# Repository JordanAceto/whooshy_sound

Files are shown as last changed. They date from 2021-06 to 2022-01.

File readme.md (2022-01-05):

# Effects pedal for making whooshy filter and phaser sweeping sounds

## This pedal accommodates various VCF plug-in boards, and contains rich modulation features.

whooshy sound pedal

### [SCHEMATIC](https://github.com/JordanAceto/whooshy_sound/blob/main/hardware/main_pcb/construction_docs/whooshy_sound_main_pcb_schematic.pdf)

---

### Features:
- Guitar pedal style stomp box.
- Can accept a wide variety of [filter plug-in boards](https://github.com/JordanAceto/VCF_plug_in_boards).
    - For guitars and other instrument-level signals I recommend starting with the "2164" filter plug-in boards, because these have very low noise and CV feedthrough.
    - Other plug-in boards will work for guitars, but may be a little noisier and thumpier than you wish. Try them out, they vary.
    - If you're using this in an effects loop or after a preamp, it doesn't matter as much and any of them will probably be fine.
- Manual frequency and resonance controls.
- Digitally generated LFO with morphing waveshaper, smoothly crossfades from triangle to sine to square to sample & hold.
- Analog envelope follower for when you want to quack and bwow instead of whoosh.

---

### Status of the project:

Revision | schematic | pcb layout | firmware | built and tested | safe to order boards
------|--------------|-----------|------------|---------|---------
0.1 | &#9745; | &#9745; | &#9745; | &#9745; | &#9745;

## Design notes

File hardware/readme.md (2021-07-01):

# The hardware for the pedal.

- The [main pcb](https://github.com/JordanAceto/whooshy_sound/tree/main/hardware/main_pcb) is the heart of the project.

- Once the pedal is built, you need at least one [VCF plug-in board](https://github.com/JordanAceto/VCF_plug_in_boards/tree/0e87489fe4cad95ea398019b08850a9033277694) to complete the project.

- Various filter plug-in boards can be swapped in and out to experiment with sounds.

- The [front panel](https://github.com/JordanAceto/whooshy_sound/tree/main/hardware/front_panel) and [jack panel](https://github.com/JordanAceto/whooshy_sound/tree/main/hardware/jack_panel) are simple pcb panels as a cheap way to get an ok looking finished project.

- To build the pedal, you'll need flying wires from the main pcb to the 1/4" jacks, 9 volt DC power entry, and bypass footswitch. A wiring diagram for this is in the [offboard wiring](https://github.com/JordanAceto/whooshy_sound/tree/main/hardware/offboard_wiring) directory.

- [Drill guides](https://github.com/JordanAceto/whooshy_sound/tree/main/hardware/drill_guides) may help when drilling out the Hammond 1590BBS enclosure.

- Note that with a plug-in board installed the circuitboards are just a _liiiiitle_ bit too tall to fit into a Hammond 1590BB. Make sure to get an enclosure that is deep enough, like a 1590BB**S**.

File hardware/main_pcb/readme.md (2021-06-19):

# Main PCB

## The main PCB contains:
- input and output audio buffers
- a software generated LFO
- an envelope follower
- a port which accepts various VCF plug-in boards
- power supply components

---

### PCB front view:
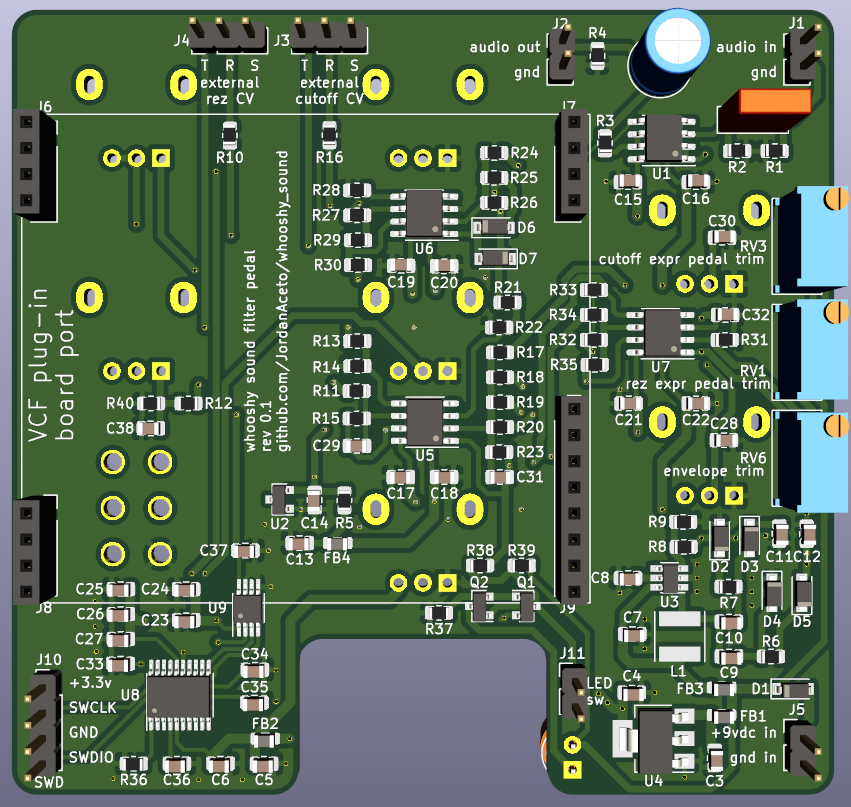
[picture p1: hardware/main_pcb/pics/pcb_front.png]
main PCB front view
 

---

### PCB rear view:
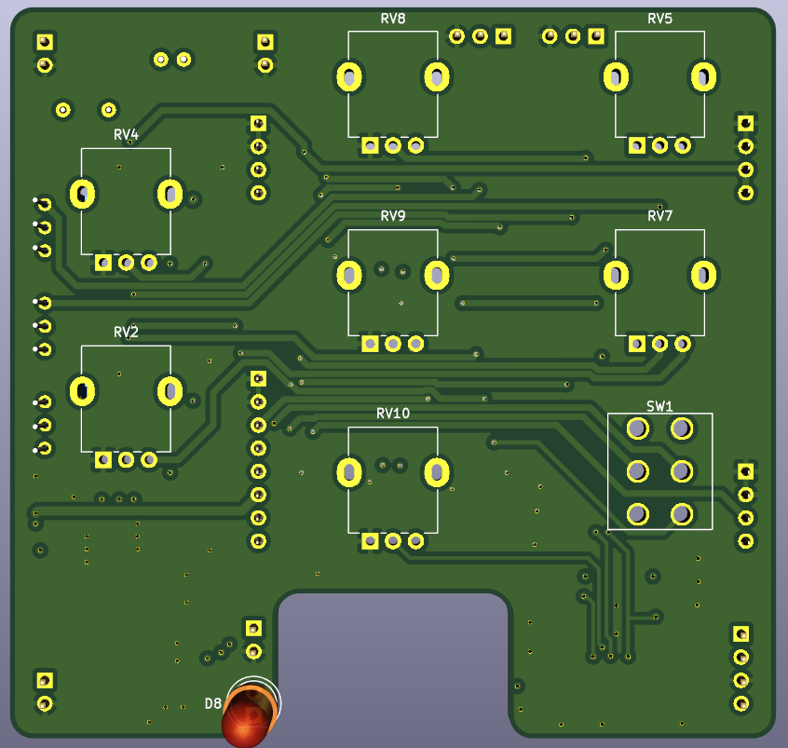
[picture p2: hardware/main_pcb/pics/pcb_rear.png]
main PCB rear view


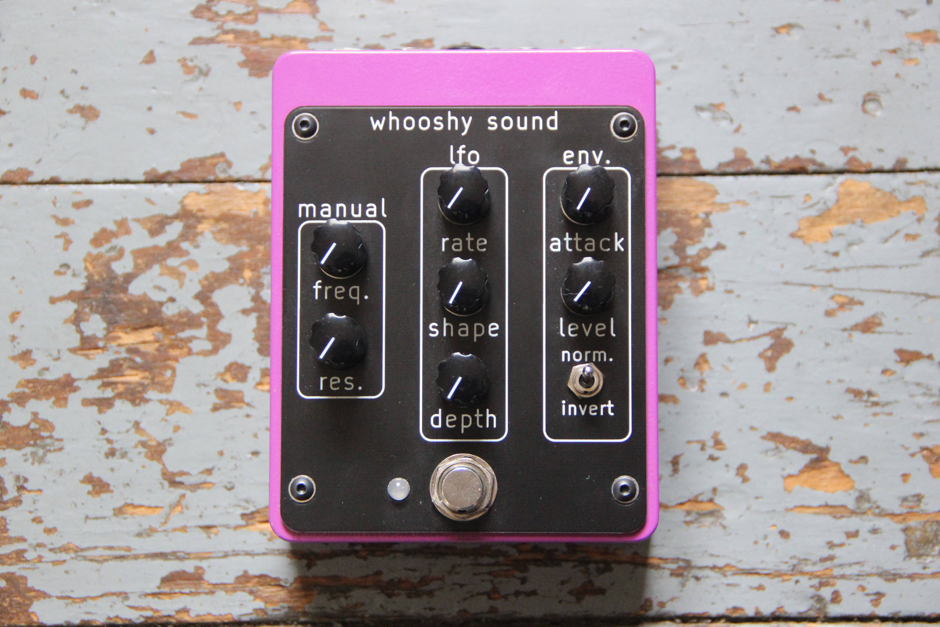
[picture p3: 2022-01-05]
hardware/pics/whooshy_sound_front.JPG

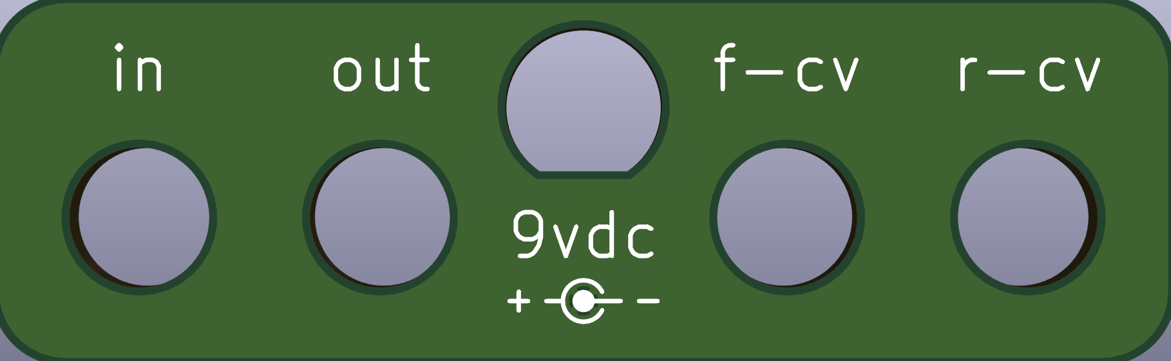
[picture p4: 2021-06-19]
hardware/jack_panel/pics/jack_panel.png

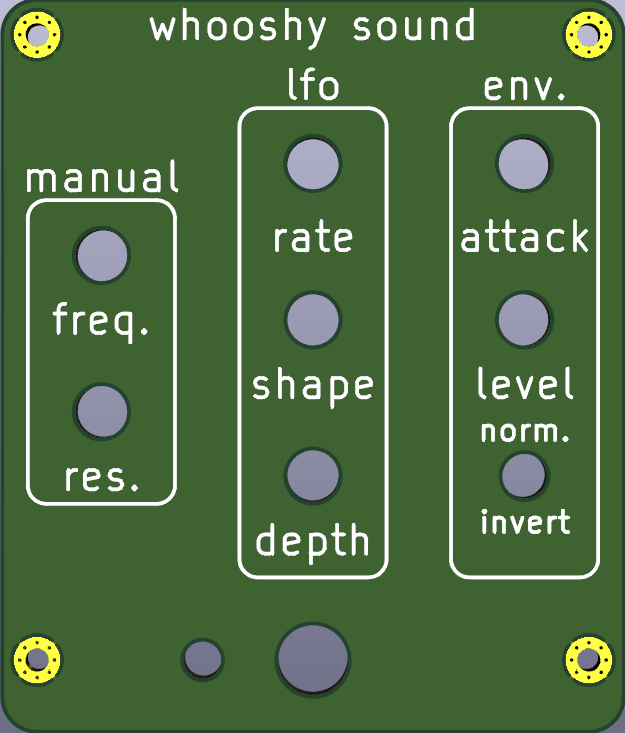
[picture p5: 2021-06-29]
hardware/front_panel/pics/front_panel.png

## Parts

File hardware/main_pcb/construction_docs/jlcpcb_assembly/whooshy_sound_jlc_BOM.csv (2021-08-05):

Comment | Designator | Footprint | LCSC Part Number
TL072 | U7,U6,U5,U1 | SOIC-8_3.9x4.9_1.27P | C6961
1k2 | R40, R3, R30 | 0805 | C17379
2k7 | R12 | 0805 | C17530
1M | R39,R4 | 0805 | C17514
100k | R38,R35,R33,R32,R29,R28,R27,R26,R25,R24,R23,R19,R18,R15 | 0805 | C17407
100R | R37 | 0805 | C17408
MMBT3904 | Q2,Q1 | SOT-23-3 | C20526
10k | R36,R16,R10 | 0805 | C17414
270k | R34, R20 | 0805 | C17589
2k2 | R31,R5 | 0805 | C17520
15k | R22 | 0805 | C17475
120k | R21 | 0805 | C17436
68k | R13 | 0805 | C17801
220k | R17,R11 | 0805 | C17556
27k | R14 | 0805 | C17593
1R | R7,R6 | 0805 | C25271
2M2 | R2,R1 | 0805 | C26113
Bead | FB4,FB3,FB2,FB1 | 0805 | C1015
1N4148W | D7,D6 | SOD-123 | C81598
B5819W | D1 | SOD-123 | C8598
1u | C37,C10,C9,C5 | 0805 | C28323
100n | C36,C35,C34,C33,C30,C28,C27,C26,C24,C22,C21,C20,C19,C18,C17,C16,C15,C14,C13,C8,C6 | 0805 | C49678
2u2 | C32 | 0805 | C49217
22n | C31,C29 | 0805 | C1729
10u | C38, C25,C23,C4,C3 | 0805 | C15850
4u7 | C12,C11,C7 | 0805 | C1779

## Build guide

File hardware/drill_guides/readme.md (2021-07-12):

## Printable drill guides

Various file types are provided, they are all the same thing.

I have had the best luck printing to scale by opening up the .gbr file with kicads gerber-viewer and printing from there.

Make sure to measure/compare it to the actual hardware before drilling anything!



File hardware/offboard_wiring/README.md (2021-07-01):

# Offboard wiring

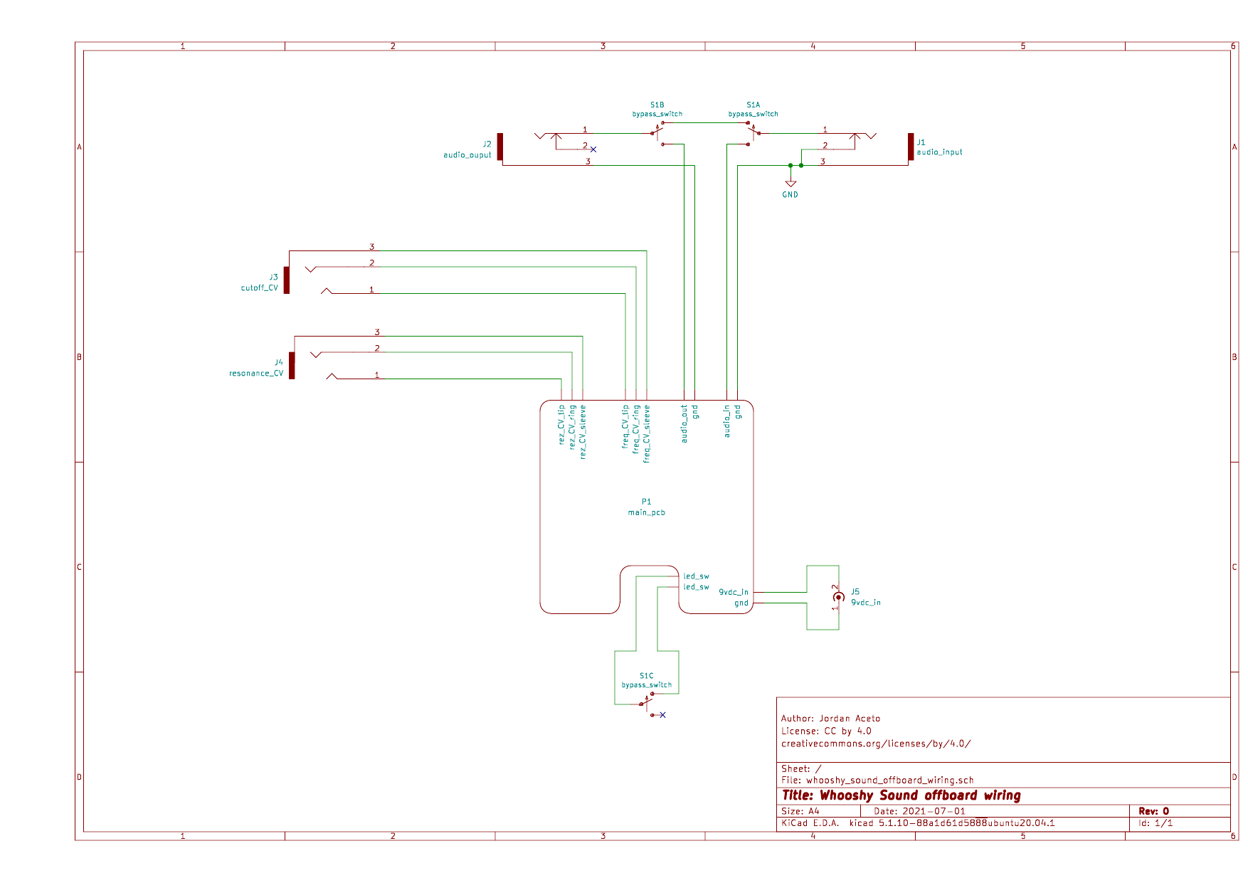
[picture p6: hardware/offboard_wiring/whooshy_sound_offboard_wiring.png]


This directory simply contains a wiring diagram for the offboard components that
are wired to the main pcb with flying wires.

These components are:
- signal input and signal output jacks
- 9vdc power input jack
- bypass switch
- cutoff-frequency and resonance CV input/expression pedal jacks

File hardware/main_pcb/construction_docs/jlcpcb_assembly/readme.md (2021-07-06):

# Files for low cost [JLCPCB smt assembly](https://jlcpcb.com/smt-assembly)

## Note that not all smt components are included! A few small parts will need to be hand soldered.

### Missing parts include:
- STM32L031F4
- MCP4821
- LT3467A
- PMEG2010 diodes
- DC-DC converter inductor
- DC-DC convererter feedback resistors
- LM4040
- LT1117

The above parts were not in stock at the time of order.

If you are using the JLCPCB assembly service in the future, check on those parts and see if they are back in stock. Also be sure to check that other parts have not gone out of stock.

The assembly saves hand soldering almost 90 parts for about ~$4.50 per board (which included the cost of the parts). Whether this is worth it or not is up to you.

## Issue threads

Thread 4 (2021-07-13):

DAC shutdown pin is wrong

JordanAceto, 2021-07-13:
D'oh, the shutdown pin for the DAC is tied to ground, but this permanently shuts down the device.

As a kludge, carefully bend pin 6 of the DAC up, and tie it to 3.3v somehow.

Please eventually respin the main pcb and fix this issue by tying pin 6 of the MCP4821 DAC to logical high instead of low.

Consider changing the footprint to SOIC8 when you do this, there is no pressing need for the smaller MSOP footprint.

JordanAceto, 2021-08-05:
Done.

Closed 2021-08-05.

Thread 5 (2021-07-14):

toggle switch and footswitch holes are too small in the front panel

JordanAceto, 2021-07-14:
The holes for the envelope-follower invert/normal switch and the bypass footswitch are a little too small on the front panel.

This is not a very big problem, because you can easily ream or drill out the holes to be slightly bigger.

Still, if you do a new batch of front panels, make the holes the correct size please.

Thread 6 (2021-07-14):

Envelope follower level pot feels off

JordanAceto, 2021-07-14:
The envelope follower level pot attenuates the envelope signal that sits in the range [0v, +2v].

When you turn it down, it goes down to zero volts.

This feels weird with the way everything is scaled, it would feel more natural if it turned "down" towards +1 volt (the middle of its range), squishing peaks down and pushing valleys up. This is how the LFO is attenuated, it swings between 0 and +2 volts, centered around +1 volt, and attenuates to +1 volt.

As a quick fix, cut the ground leg of the envelope follower pot and inject a +1 volt reference. This could be created by a 2.7k / 1.2k resistive voltage divider across the +3.3v rail. Put a big cap across at least one of the resistors. If you do this, consider also changing the EF level pot to 100k, the bigger the pot to more attenuation you'll get when you turn it down. There still might be some EF bleed when the pot is at a minimum.

When a pcb respin happens, consider ways of scaling the EF to accomplish the attenuation behavior described above. Maybe this means rethinking the norm/invert switch and the method of generating the offset. Perhaps the EF could swing from [-1v, +1v], centered around zero, and then get pushed up 1 volt later in the CV summing amp.

Bonus points if you can change the norm/invert switch to a single pole switch while you do this, I bet you can.

If it seems like the best way to do this is to add another opamp, you could use the other half of a dual package for the LED driver and get rid of the existing transistor LED driver.

JordanAceto, 2021-08-05:
Done, centered envelope follower around +1v. I did not change the invert switch to a single pole version, but I thought about how to do it right after I ordered boards. Just apply the +1v reference directly to the non-inverting input of the opamp, and get rid of the bias applying resistor that gets switched in. Oh well, add this in some other time.

Closed 2021-08-05.

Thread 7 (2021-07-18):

Envelope follower invert switch should say "up/down"

JordanAceto, 2021-07-18:
On the front panel, the envelope follower invert switch is labeled "norm./invert".

To be more intuitive to users, this should be changed to "up/down".

Not a big deal, change it if you're making other changes to the front panel also.

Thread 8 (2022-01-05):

Envelope follower invert switch does not need to be DPDT

JordanAceto, 2022-01-05:
The envelope follower normal/invert switch is currently a DPDT switch.

The same thing could be accomplished with a SPDT or SPST switch.

Instead of grounding the non-inverting opamp input and applying a bias to the inverting input, just short the non-inverting input to a +1 volt DC reference or leave it open.

This is not a pressing issue, just consider it if/when a board revision happens.

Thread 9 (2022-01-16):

CV signals should be clipped to [0v .. +2v]

JordanAceto, 2022-01-16:
The useful range of the cutoff CV is [0v .. +2v]. Voltages outside this range that reach the VCF plug-in boards will not cause any electrical harm, but it can sometimes cause thumping or other offset issues depending on the filter. This especially happens when the envelope follower trim is set for higher gain than is necessary and the envelope follower is turned up really high.

The user can avoid bad sounding settings by adjusting things correctly, but it would be an improvement to prevent them from making big DC thumps in the first place.

Please add some  kind of clamping circuit so that the control voltages can not exceed the range [0v .. +2v]. A half a volt or so in either direction is also fine, this is not a precise clamp, just a way to stop grossly wrong control signals from hitting the filters.

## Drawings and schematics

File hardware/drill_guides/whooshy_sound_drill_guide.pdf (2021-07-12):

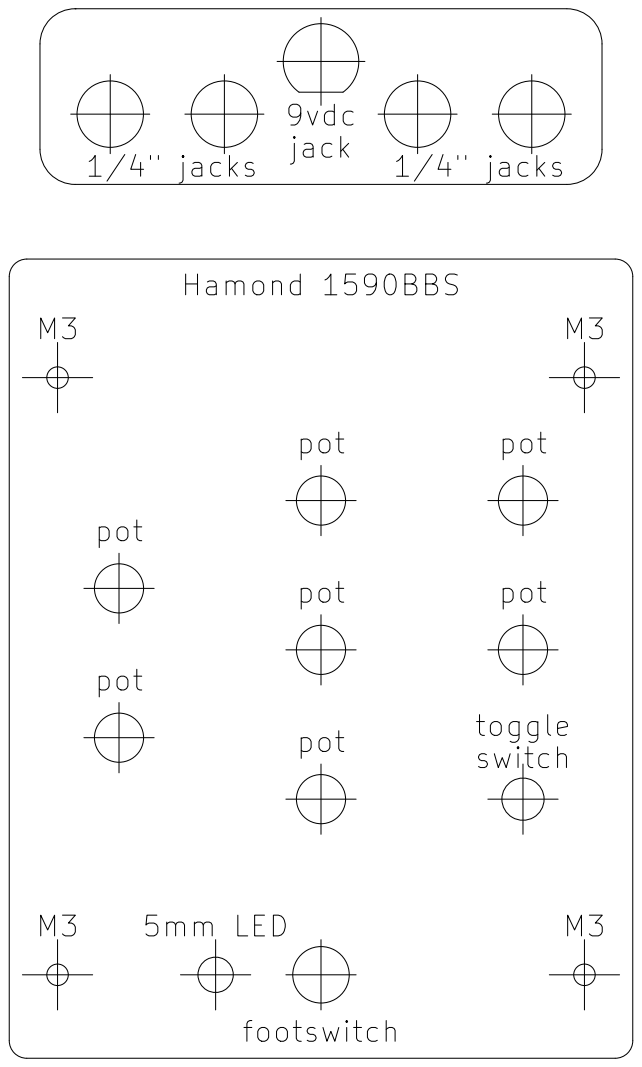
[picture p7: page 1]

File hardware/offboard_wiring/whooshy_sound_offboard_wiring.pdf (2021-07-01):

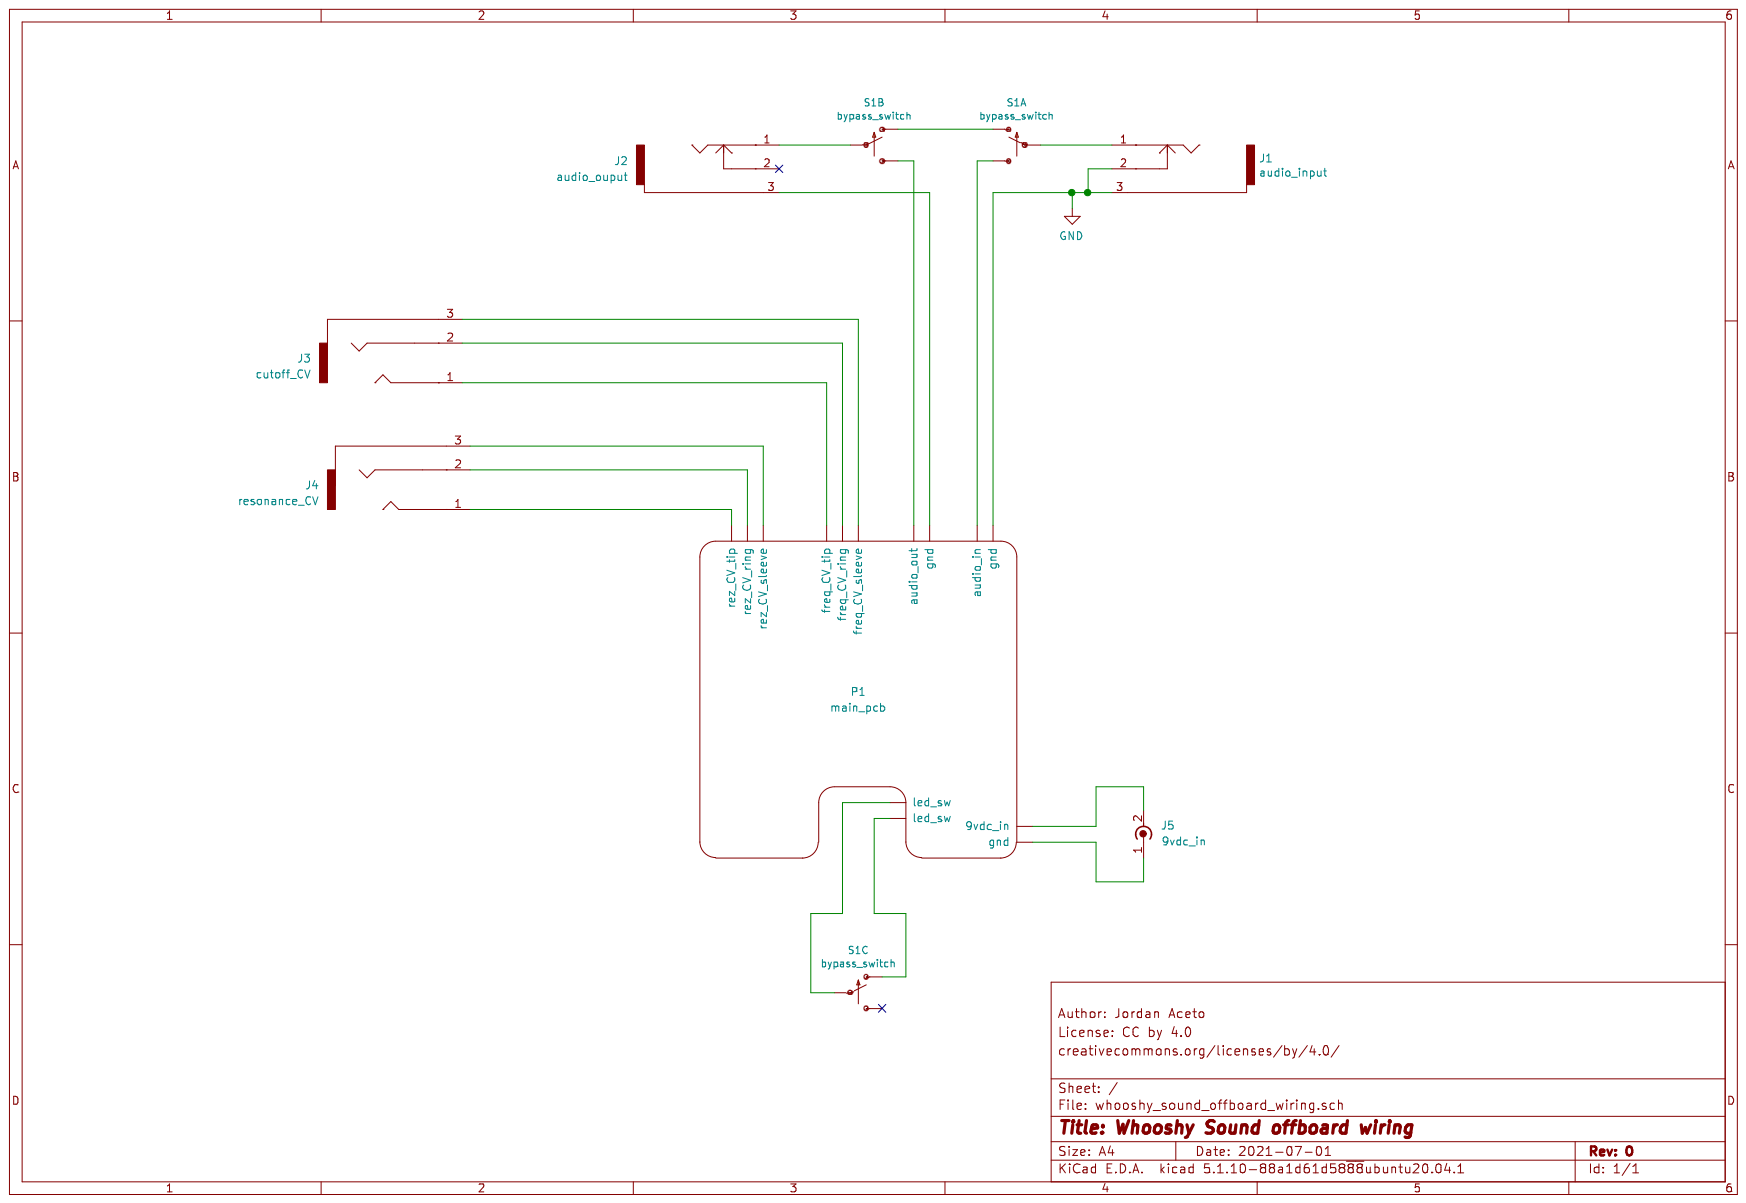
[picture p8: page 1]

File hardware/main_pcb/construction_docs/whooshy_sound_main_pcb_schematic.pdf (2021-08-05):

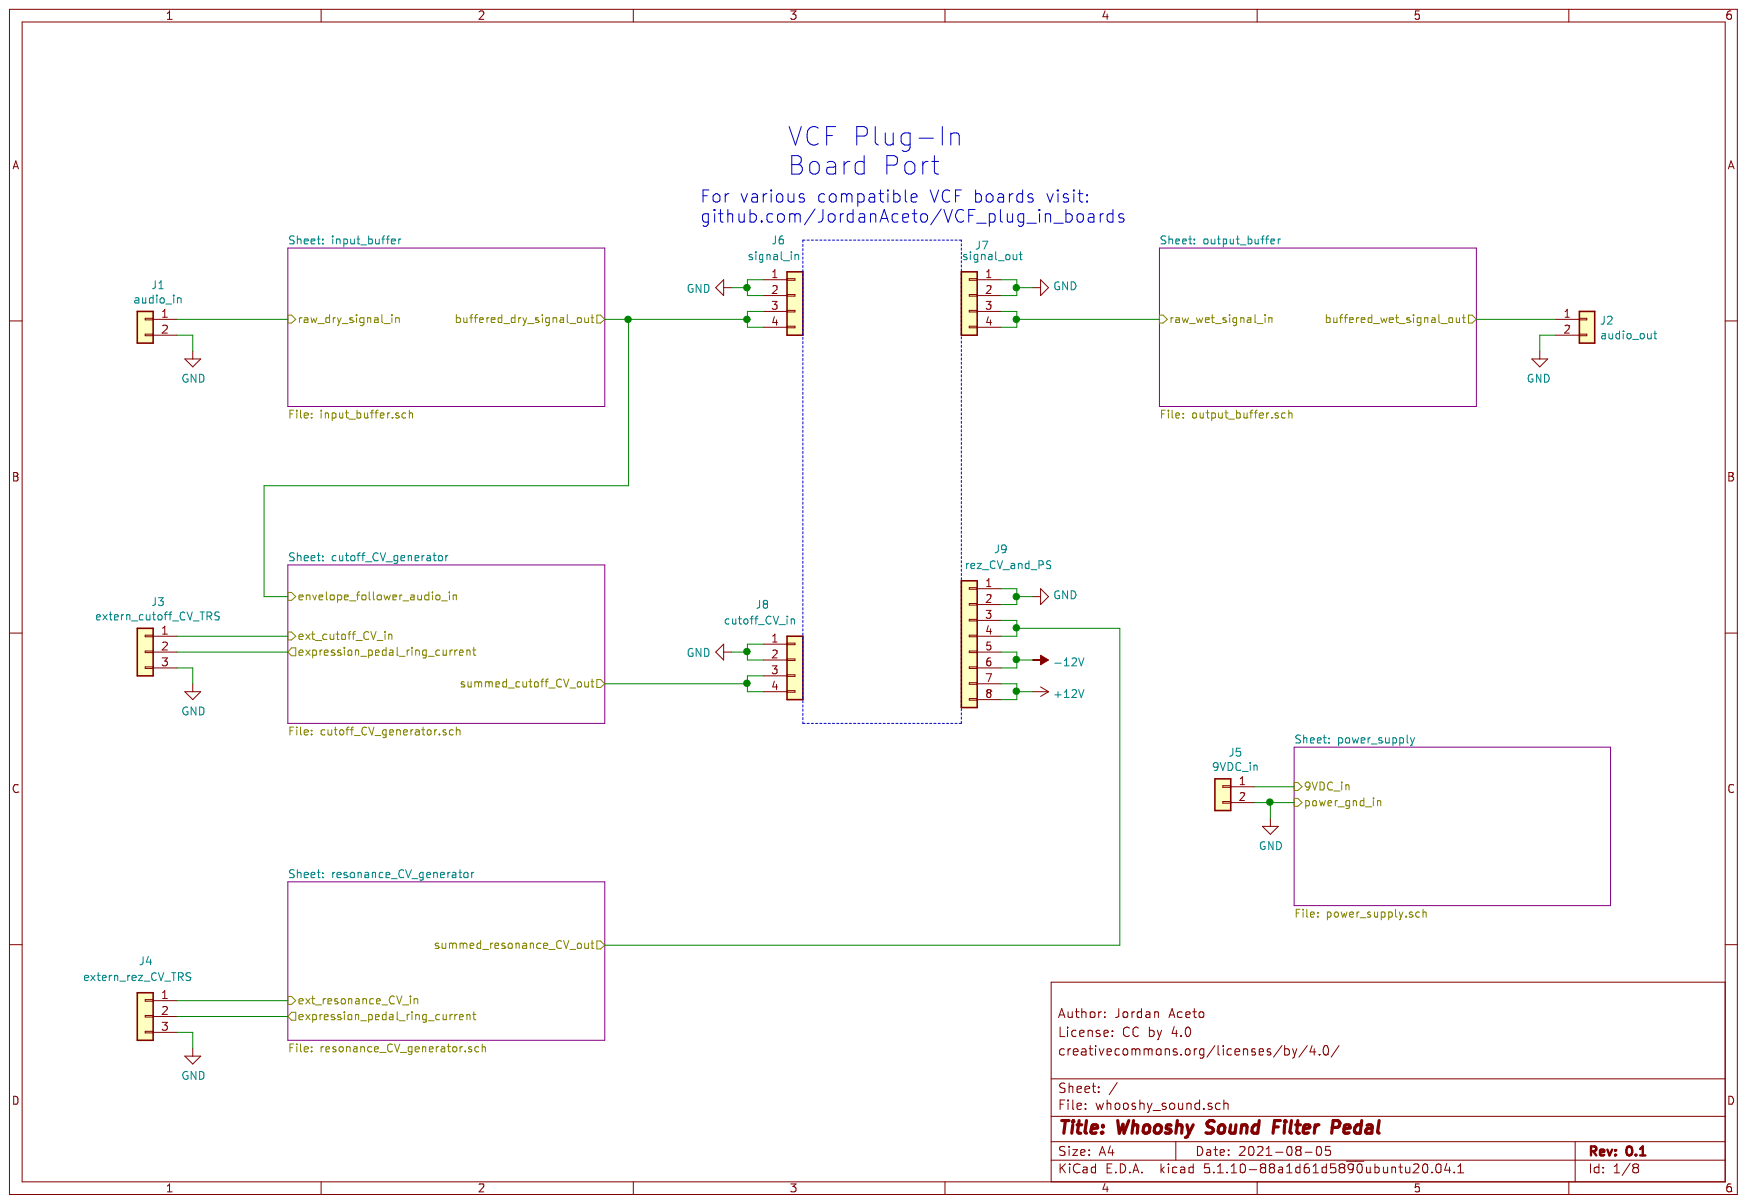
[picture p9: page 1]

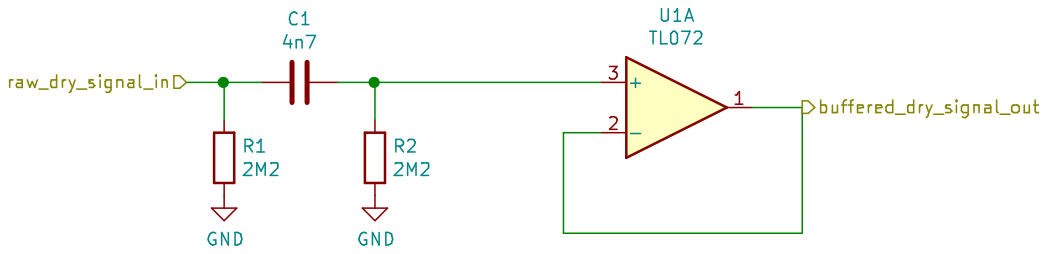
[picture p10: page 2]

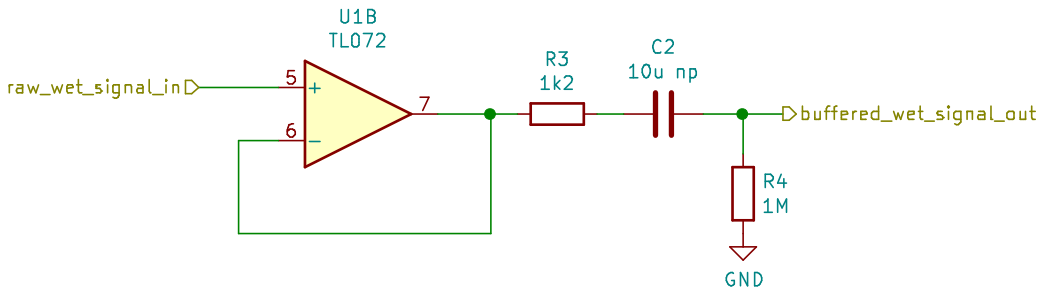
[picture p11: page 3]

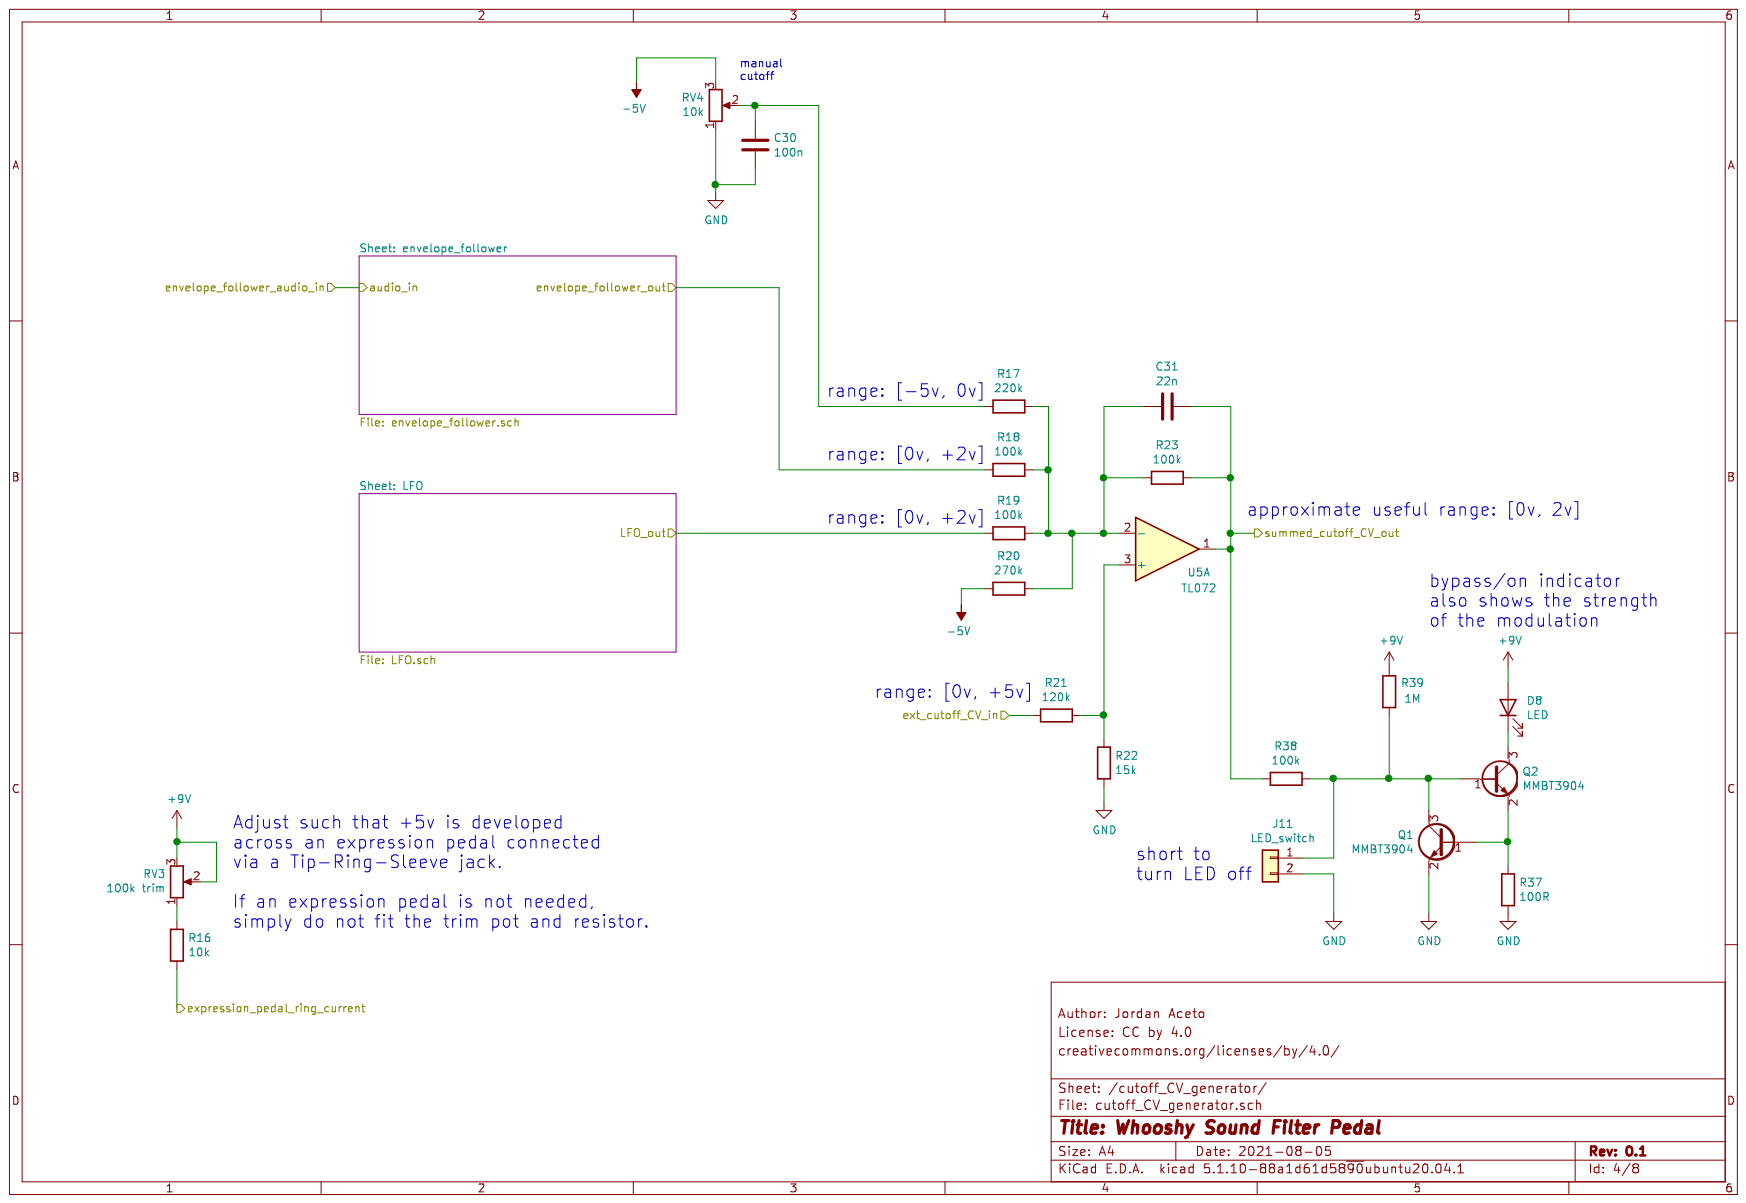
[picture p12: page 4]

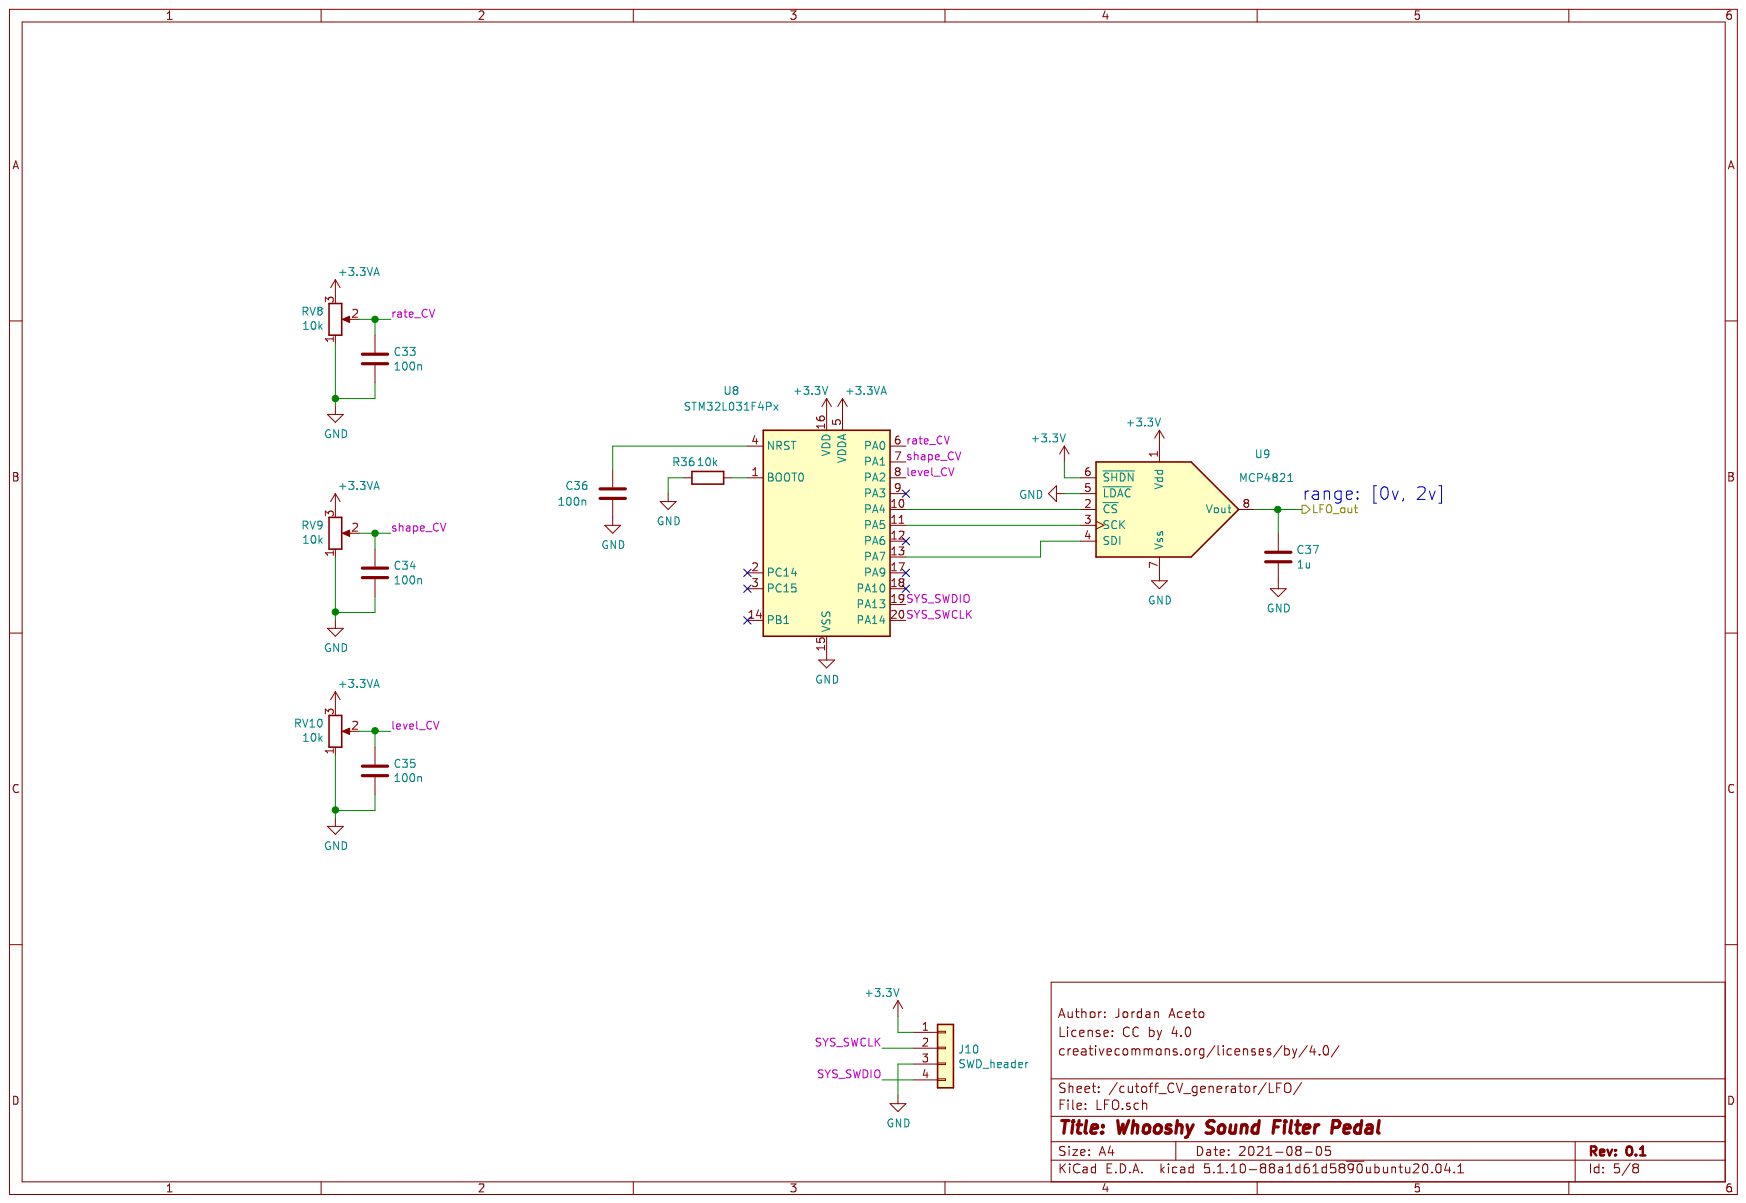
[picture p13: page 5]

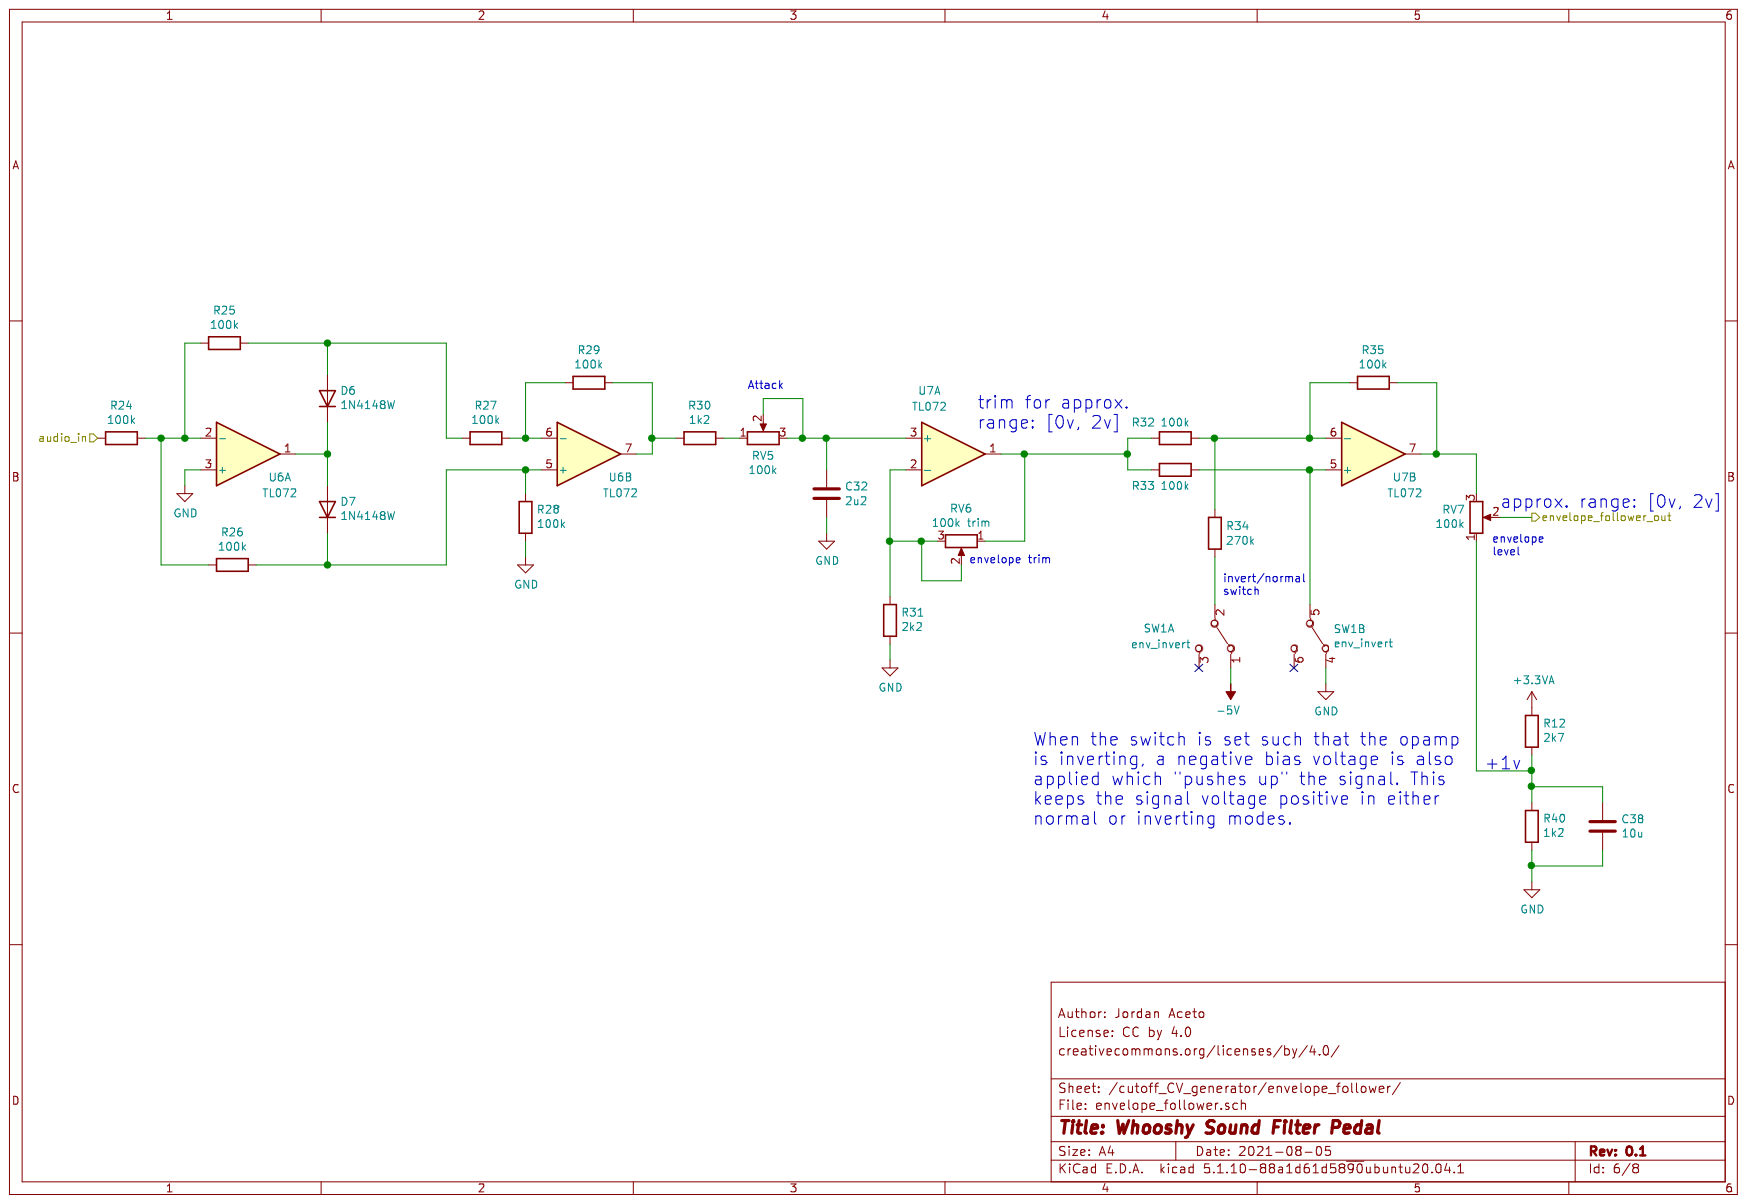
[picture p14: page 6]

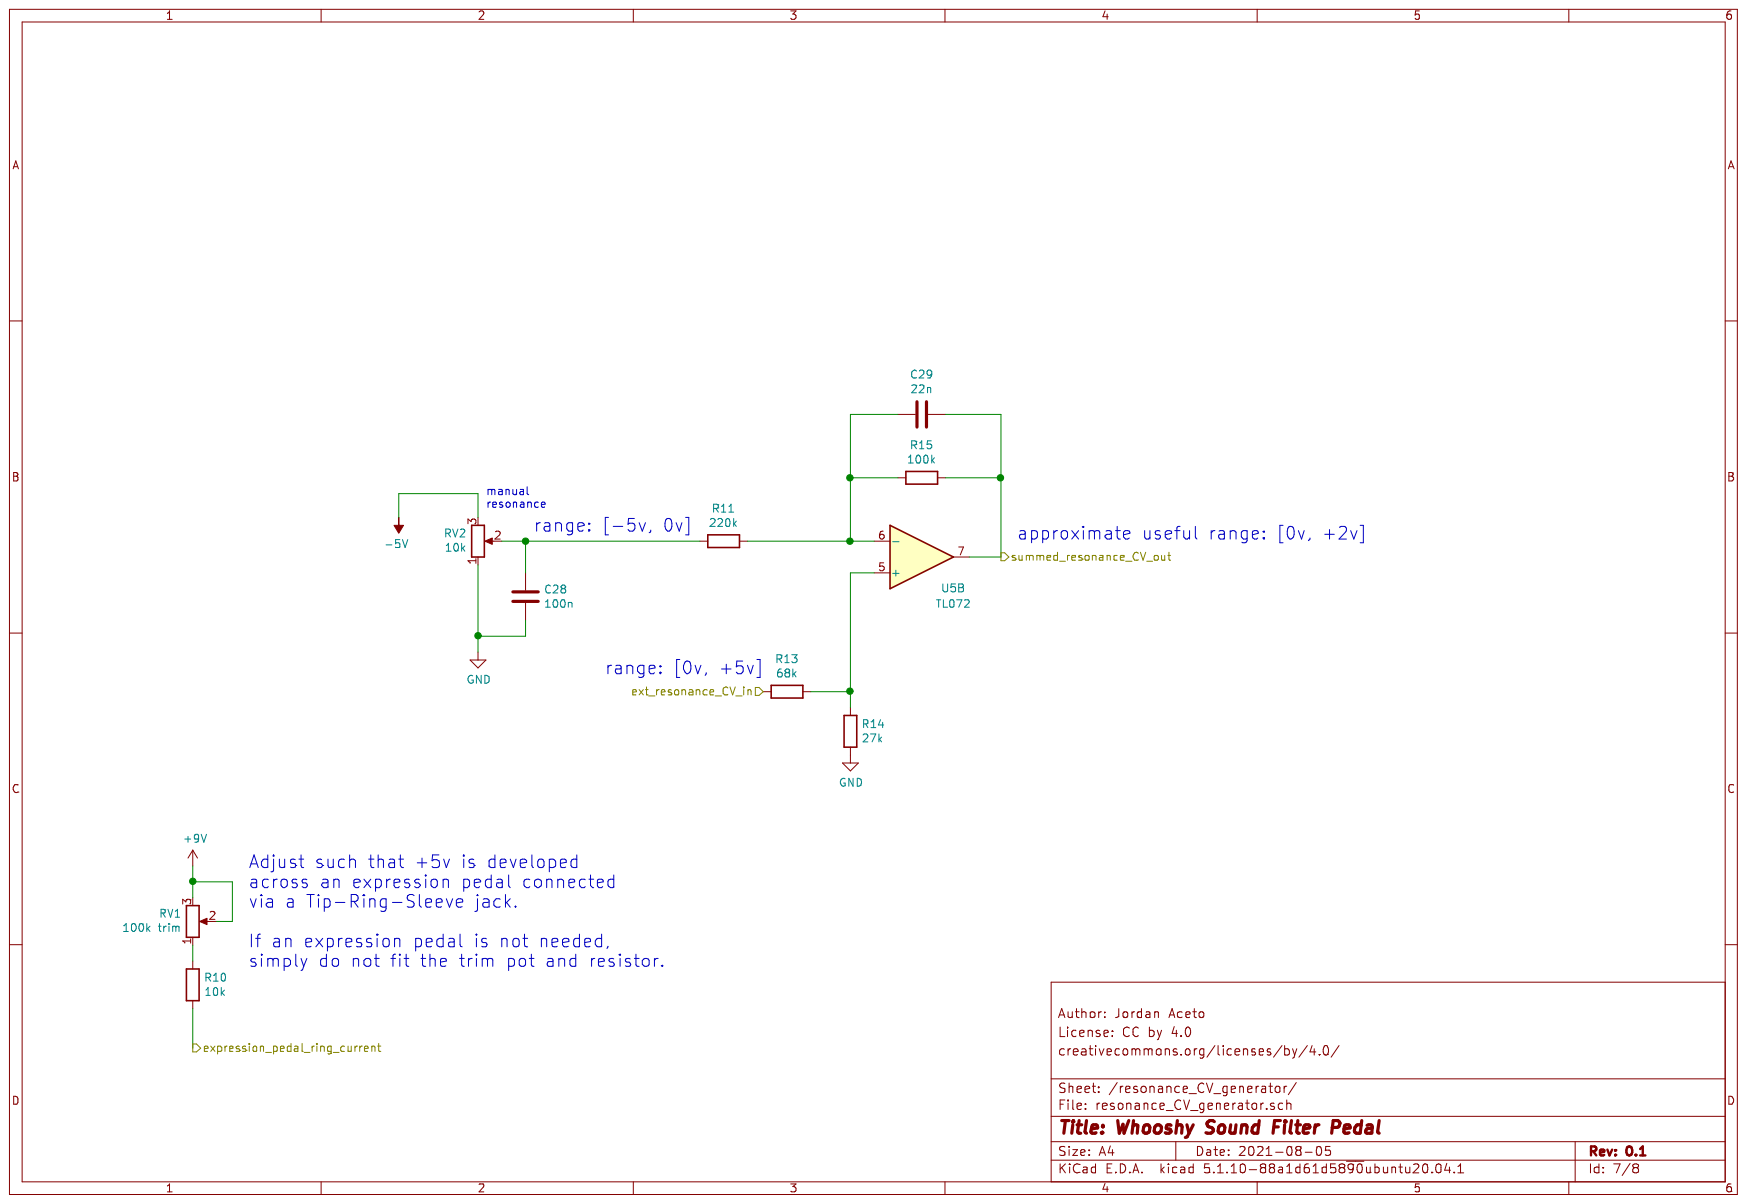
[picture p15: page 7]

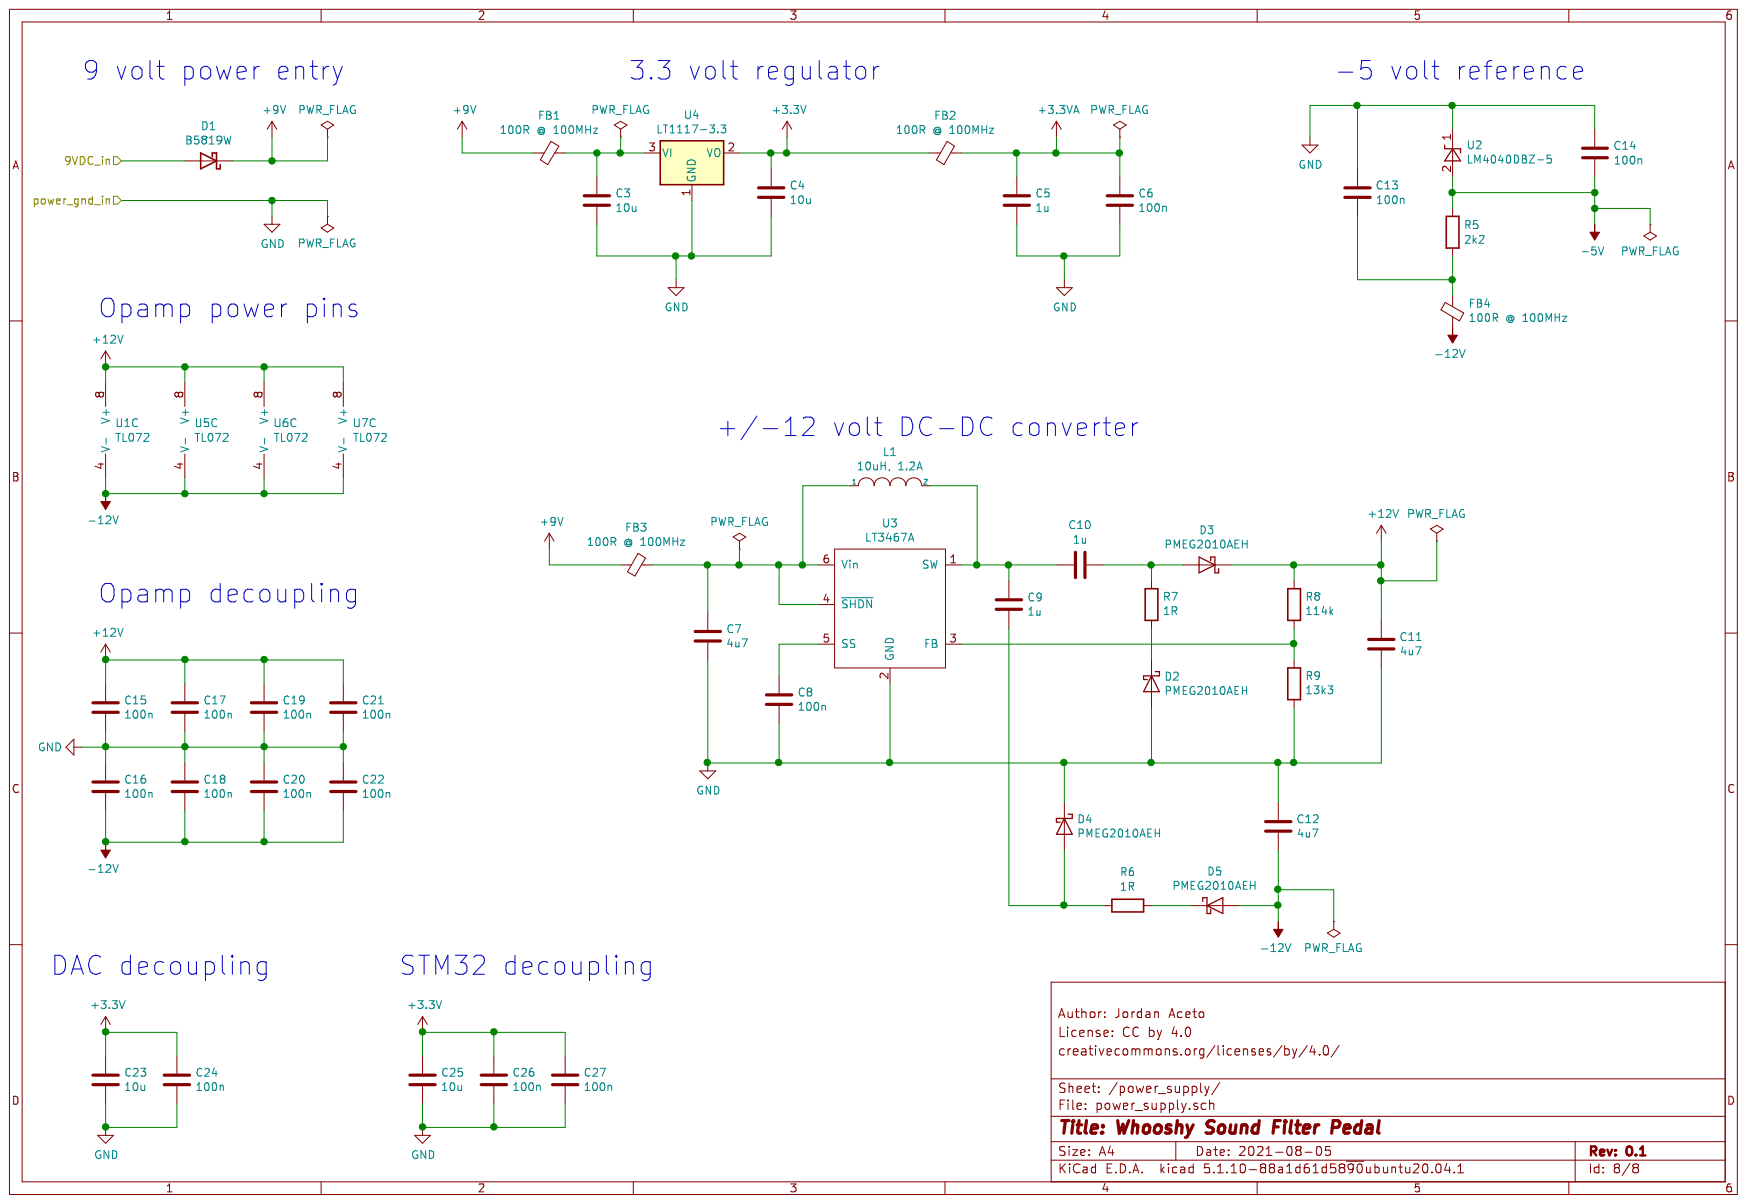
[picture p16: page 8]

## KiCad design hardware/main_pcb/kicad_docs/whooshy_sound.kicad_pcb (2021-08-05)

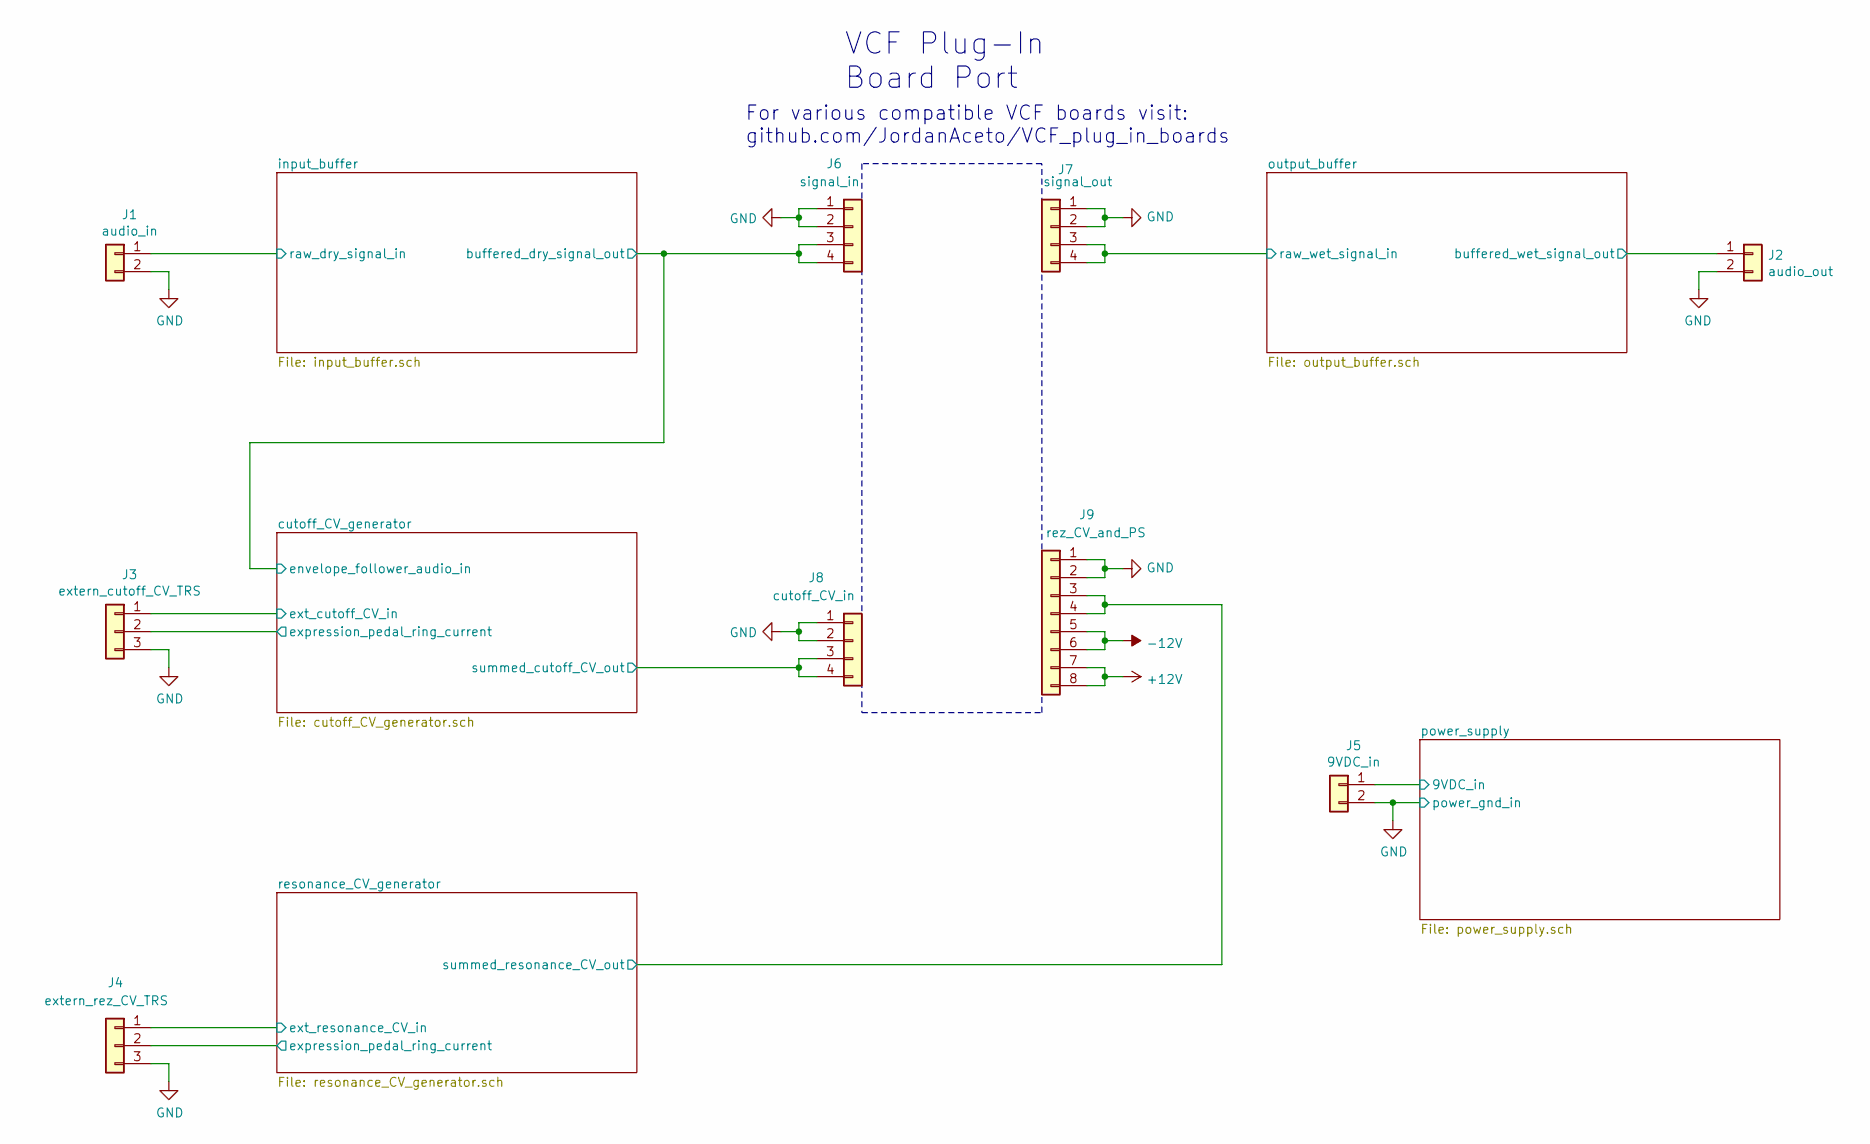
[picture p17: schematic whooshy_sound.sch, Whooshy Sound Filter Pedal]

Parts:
J1: audio_in; PinHeader_1x02_P2.54mm_Vertical
J2: audio_out; PinHeader_1x02_P2.54mm_Vertical
J3: extern_cutoff_CV_TRS; PinHeader_1x03_P2.54mm_Vertical
J4: extern_rez_CV_TRS; PinHeader_1x03_P2.54mm_Vertical
J5: 9VDC_in; PinHeader_1x02_P2.54mm_Vertical
J6: signal_in; PinSocket_1x04_P2.54mm_Vertical
J7: signal_out; PinSocket_1x04_P2.54mm_Vertical
J8: cutoff_CV_in; PinSocket_1x04_P2.54mm_Vertical
J9: rez_CV_and_PS; PinSocket_1x08_P2.54mm_Vertical

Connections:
+12V: J9.7, J9.8; also elsewhere on the board
-12V: J9.5, J9.6; also elsewhere on the board
/cutoff_CV_generator/expression_pedal_ring_current: J3.2; also elsewhere on the board
/cutoff_CV_generator/ext_cutoff_CV_in: J3.1; also elsewhere on the board
/cutoff_CV_generator/summed_cutoff_CV_out: J8.3, J8.4; also elsewhere on the board
/input_buffer/buffered_dry_signal_out: J6.3, J6.4; also elsewhere on the board
/input_buffer/raw_dry_signal_in: J1.1; also elsewhere on the board
/output_buffer/buffered_wet_signal_out: J2.1; also elsewhere on the board
/output_buffer/raw_wet_signal_in: J7.3, J7.4; also elsewhere on the board
/power_supply/9VDC_in: J5.1; also elsewhere on the board
/resonance_CV_generator/expression_pedal_ring_current: J4.2; also elsewhere on the board
/resonance_CV_generator/ext_resonance_CV_in: J4.1; also elsewhere on the board
/resonance_CV_generator/summed_resonance_CV_out: J9.3, J9.4; also elsewhere on the board
GND: J1.2, J2.2, J3.3, J4.3, J5.2, J6.1, J6.2, J7.1, J7.2, J8.1, J8.2, J9.1, J9.2; also elsewhere on the board

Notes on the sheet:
VCF Plug-In Board Port
For various compatible VCF boards visit: github.com/JordanAceto/VCF_plug_in_boards

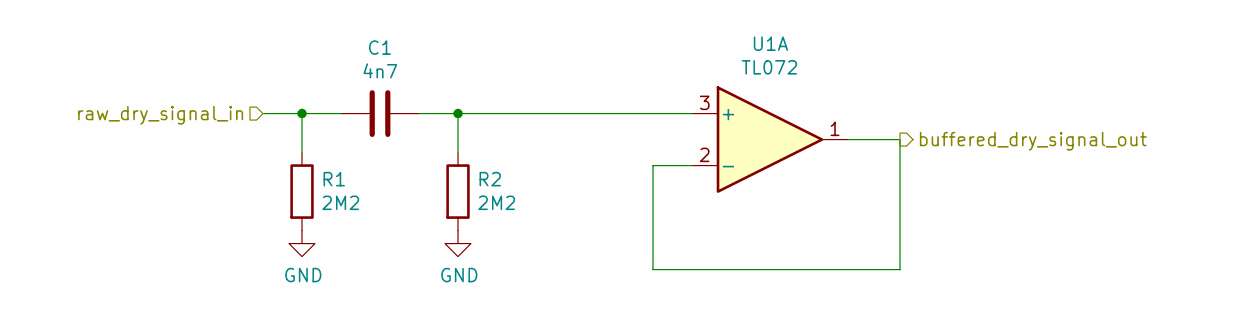
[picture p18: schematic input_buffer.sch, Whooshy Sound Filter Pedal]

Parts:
C1: 4n7; C_Rect_L7.0mm_W2.5mm_P5.00mm
R1, R2: 2M2; R_0805_2012Metric
U1: TL072; SOIC-8_3.9x4.9mm_P1.27mm

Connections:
/input_buffer/buffered_dry_signal_out: U1.1, U1.2 (-); also elsewhere on the board
/input_buffer/raw_dry_signal_in: C1.2, R1.1; also elsewhere on the board
GND: R1.2, R2.2; also elsewhere on the board
unnamed: C1.1, R2.1, U1.3 (+)

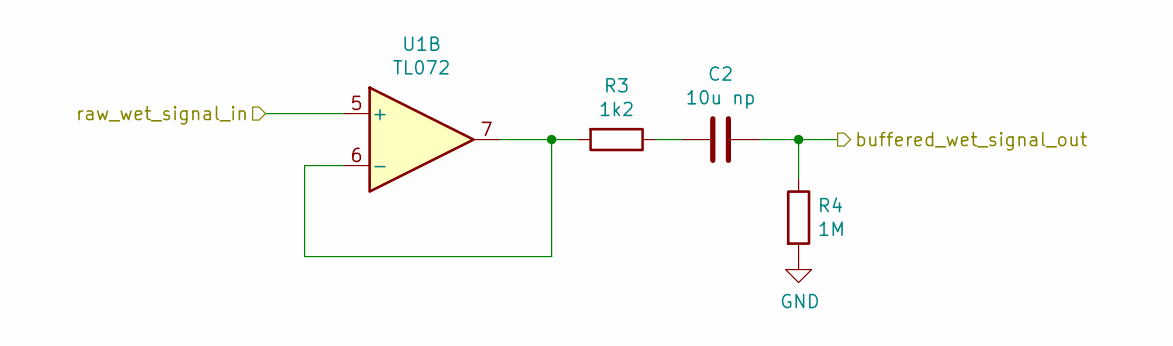
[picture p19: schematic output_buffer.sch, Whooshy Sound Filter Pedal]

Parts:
C2: 10u np; C_Radial_D6.3mm_H11.0mm_P2.50mm
R3: 1k2; R_0805_2012Metric
R4: 1M; R_0805_2012Metric
U1: TL072; SOIC-8_3.9x4.9mm_P1.27mm

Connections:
/output_buffer/buffered_wet_signal_out: C2.1, R4.1; also elsewhere on the board
/output_buffer/raw_wet_signal_in: U1.5 (+); also elsewhere on the board
GND: R4.2; also elsewhere on the board
unnamed: C2.2, R3.1
unnamed: R3.2, U1.6 (-), U1.7

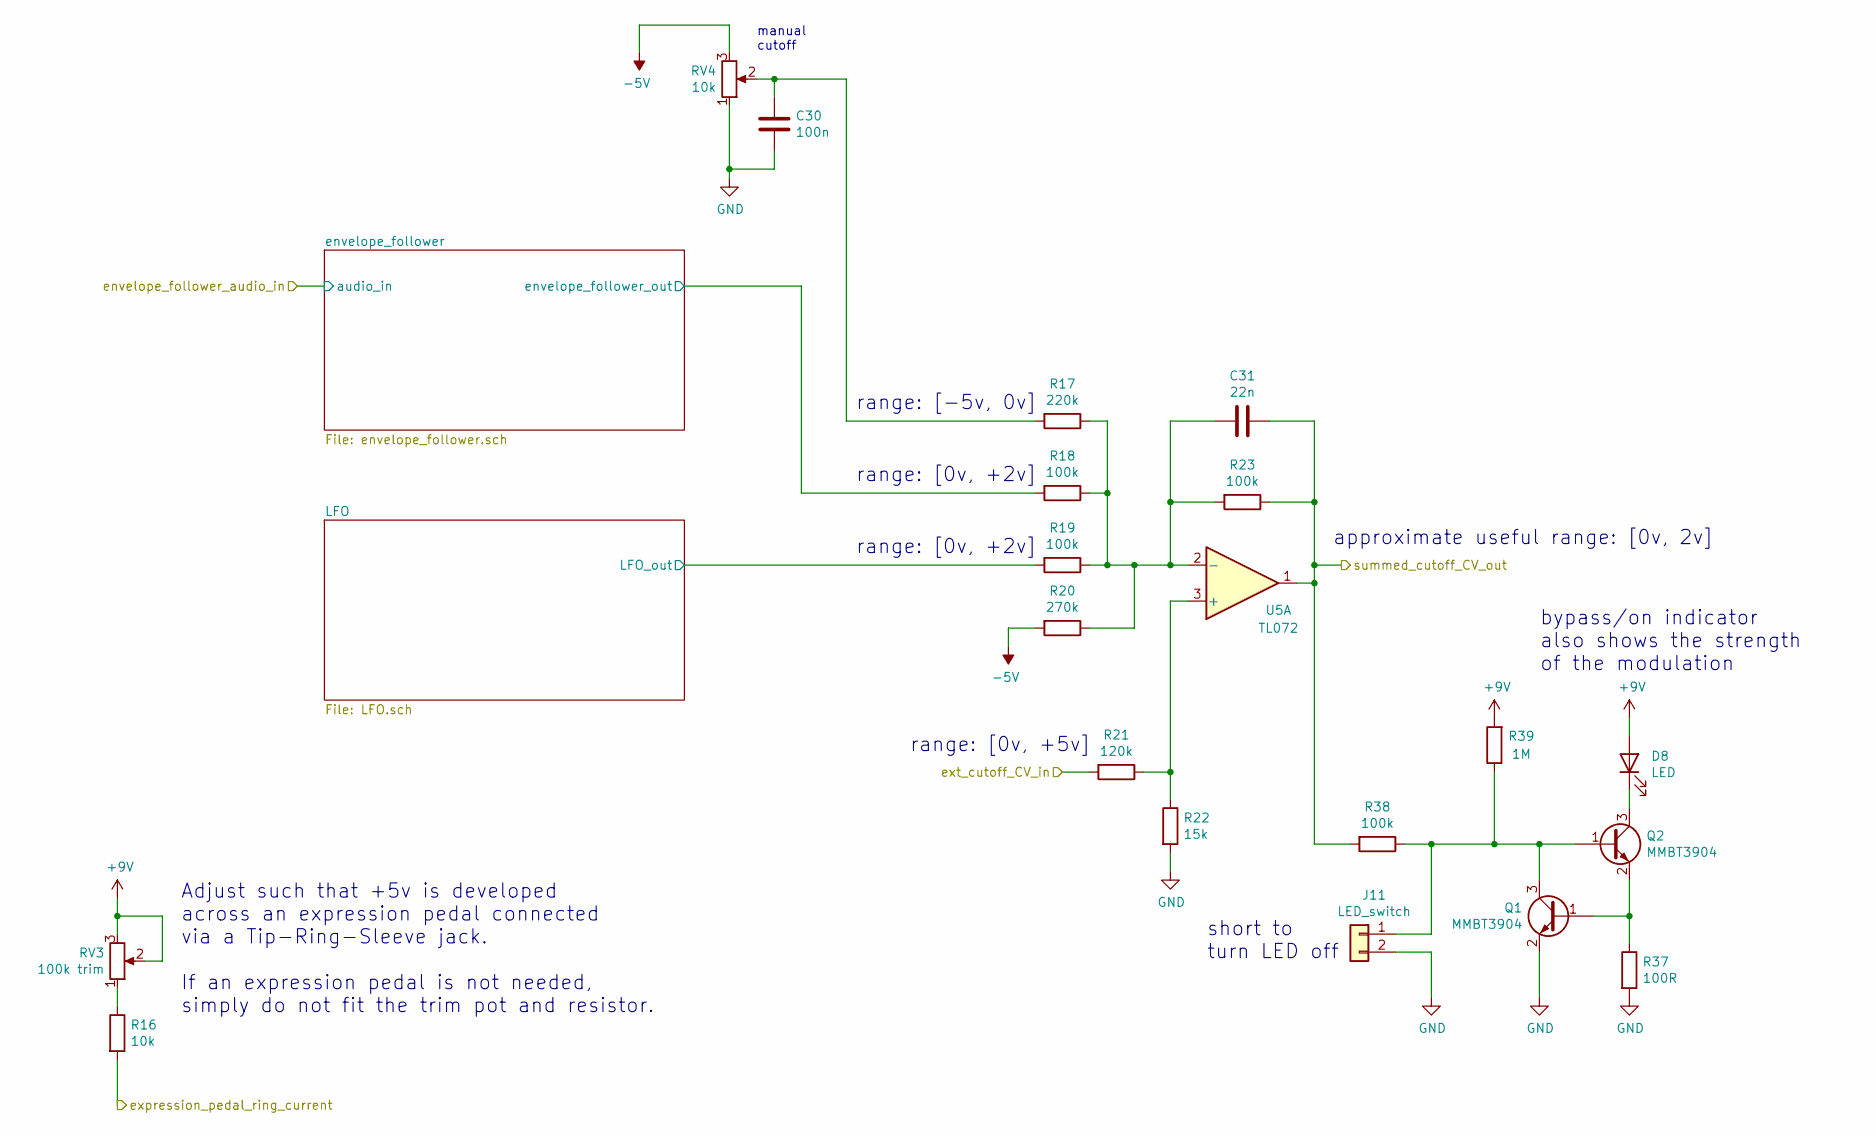
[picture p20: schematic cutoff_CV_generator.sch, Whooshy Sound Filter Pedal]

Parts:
C30: 100n; C_0805_2012Metric
C31: 22n; C_0805_2012Metric
D8: LED; LED_D5.0mm
J11: LED_switch; PinHeader_1x02_P2.54mm_Vertical
Q1, Q2: MMBT3904; SOT-23
R16: 10k; R_0805_2012Metric
R17: 220k; R_0805_2012Metric
R18, R19, R23, R38: 100k; R_0805_2012Metric
R20: 270k; R_0805_2012Metric
R21: 120k; R_0805_2012Metric
R22: 15k; R_0805_2012Metric
R37: 100R; R_0805_2012Metric
R39: 1M; R_0805_2012Metric
RV3: 100k trim; Potentiometer_Bourns_3296W_Vertical
RV4: 10k; Potentiometer_Alpha_RD901F-40-00D_Single_Vertical
U5: TL072; SOIC-8_3.9x4.9mm_P1.27mm

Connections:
+9V: D8.2 (A), R39.2, RV3.2, RV3.3; also elsewhere on the board
-5V: R20.2, RV4.3; also elsewhere on the board
/cutoff_CV_generator/LFO/LFO_out: R19.2; also elsewhere on the board
/cutoff_CV_generator/envelope_follower/envelope_follower_out: R18.2; also elsewhere on the board
/cutoff_CV_generator/expression_pedal_ring_current: R16.2; also elsewhere on the board
/cutoff_CV_generator/ext_cutoff_CV_in: R21.2; also elsewhere on the board
/cutoff_CV_generator/summed_cutoff_CV_out: C31.1, R23.1, R38.2, U5.1; also elsewhere on the board
GND: C30.2, J11.2, Q1.2 (E), R22.2, R37.2, RV4.1; also elsewhere on the board
unnamed: C30.1, R17.2, RV4.2
unnamed: C31.2, R17.1, R18.1, R19.1, R20.1, R23.2, U5.2 (-)
unnamed: D8.1 (K), Q2.3 (C)
unnamed: J11.1, Q1.3 (C), Q2.1 (B), R38.1, R39.1
unnamed: Q1.1 (B), Q2.2 (E), R37.1
unnamed: R16.1, RV3.1
unnamed: R21.1, R22.1, U5.3 (+)

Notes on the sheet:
range: [-5v, 0v]
range: [0v, +2v]
range: [0v, +5v]
approximate useful range: [0v, 2v]
manual cutoff
Adjust such that +5v is developed across an expression pedal connected via a Tip-Ring-Sleeve jack. If an expression pedal is not needed, simply do not fit the trim pot and resistor.
bypass/on indicator also shows the strength of the modulation
short to turn LED off

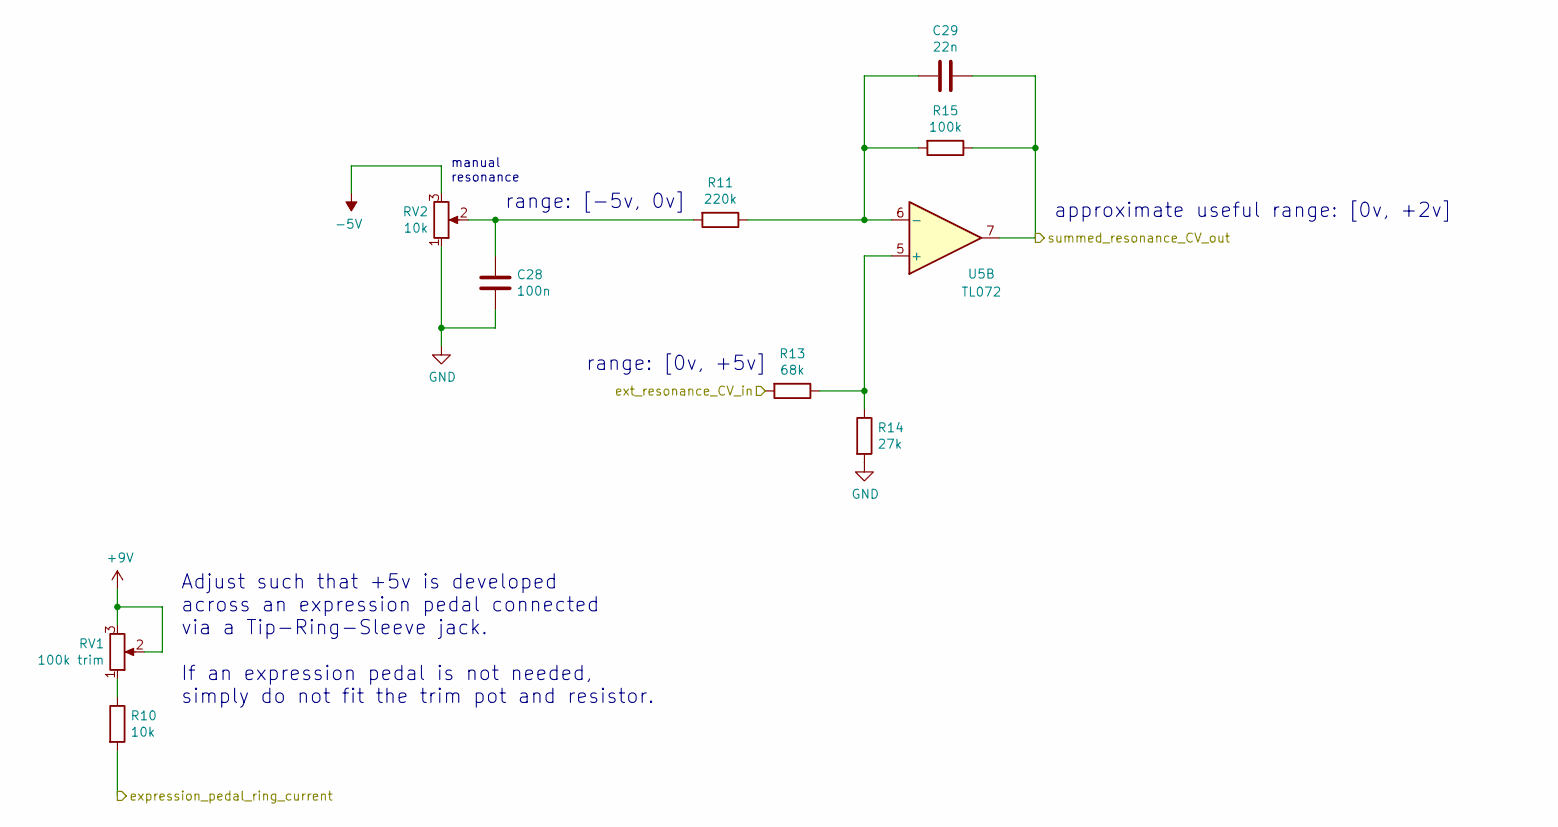
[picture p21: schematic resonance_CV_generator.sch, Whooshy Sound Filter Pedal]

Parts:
C28: 100n; C_0805_2012Metric
C29: 22n; C_0805_2012Metric
R10: 10k; R_0805_2012Metric
R11: 220k; R_0805_2012Metric
R13: 68k; R_0805_2012Metric
R14: 27k; R_0805_2012Metric
R15: 100k; R_0805_2012Metric
RV1: 100k trim; Potentiometer_Bourns_3296W_Vertical
RV2: 10k; Potentiometer_Alpha_RD901F-40-00D_Single_Vertical
U5: TL072; SOIC-8_3.9x4.9mm_P1.27mm

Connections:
+9V: RV1.2, RV1.3; also elsewhere on the board
-5V: RV2.3; also elsewhere on the board
/resonance_CV_generator/expression_pedal_ring_current: R10.2; also elsewhere on the board
/resonance_CV_generator/ext_resonance_CV_in: R13.2; also elsewhere on the board
/resonance_CV_generator/summed_resonance_CV_out: C29.1, R15.1, U5.7; also elsewhere on the board
GND: C28.2, R14.2, RV2.1; also elsewhere on the board
unnamed: C28.1, R11.2, RV2.2
unnamed: C29.2, R11.1, R15.2, U5.6 (-)
unnamed: R10.1, RV1.1
unnamed: R13.1, R14.1, U5.5 (+)

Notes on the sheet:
approximate useful range: [0v, +2v]
range: [-5v, 0v]
range: [0v, +5v]
Adjust such that +5v is developed across an expression pedal connected via a Tip-Ring-Sleeve jack. If an expression pedal is not needed, simply do not fit the trim pot and resistor.
manual resonance

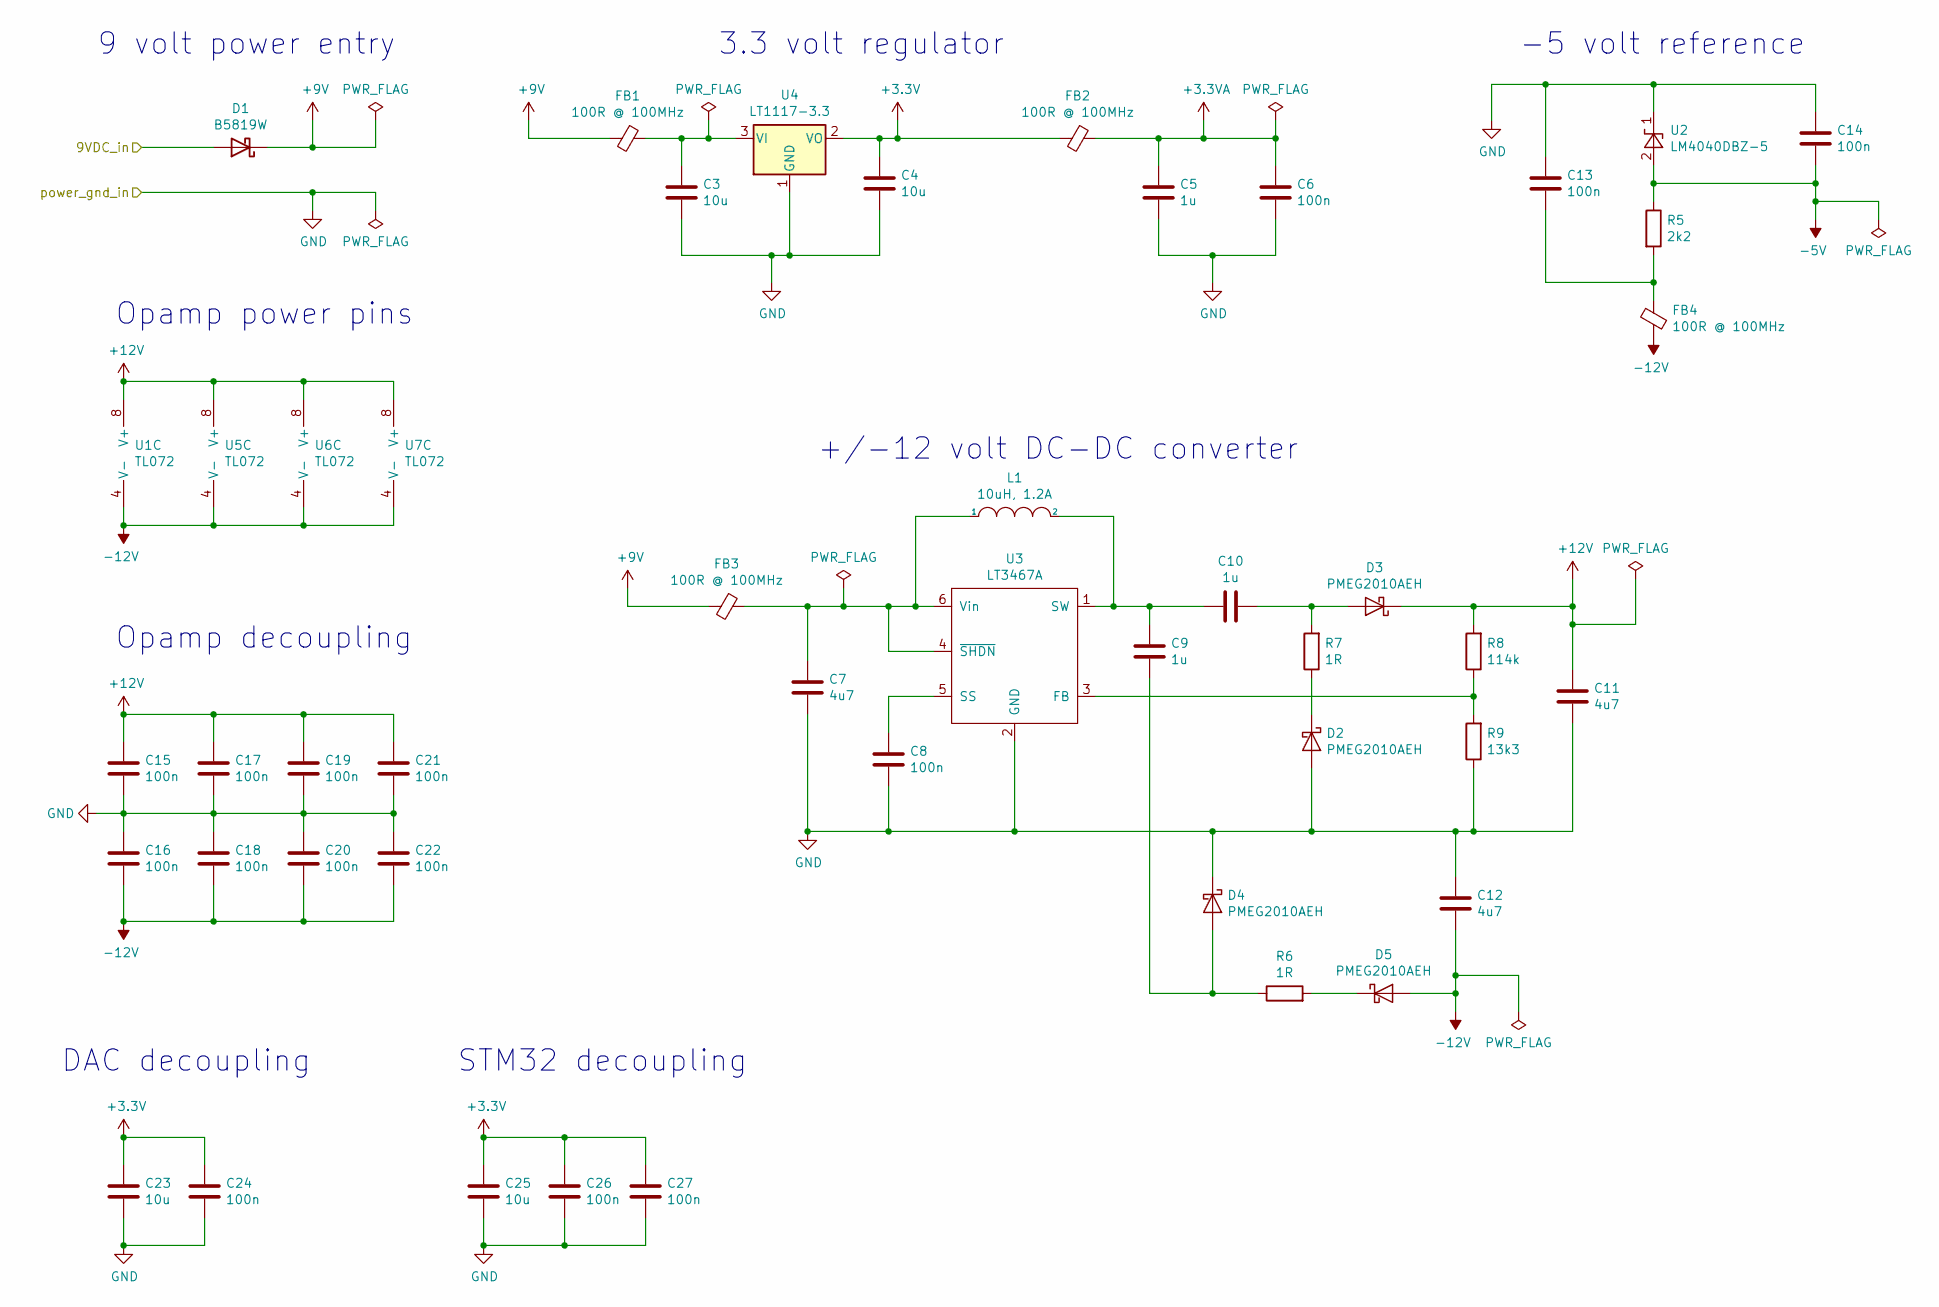
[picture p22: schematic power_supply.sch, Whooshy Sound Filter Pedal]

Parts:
C3, C4, C23, C25: 10u; C_0805_2012Metric
C5, C9, C10: 1u; C_0805_2012Metric
C6, C8, C13, C14, C15, C16, C17, C18, C19, C20, C21, C22, C24, C26, C27: 100n; C_0805_2012Metric
C7, C11, C12: 4u7; C_0805_2012Metric
D1: B5819W; D_SOD-123
D2, D3, D4, D5: PMEG2010AEH; D_SOD-123F
FB1, FB2, FB3, FB4: 100R @ 100MHz; L_0805_2012Metric
L1: 10uH, 1.2A; L_Taiyo-Yuden_NR-50xx
R5: 2k2; R_0805_2012Metric
R6, R7: 1R; R_0805_2012Metric
R8: 114k; R_0805_2012Metric
R9: 13k3; R_0805_2012Metric
U1, U5, U6, U7: TL072; SOIC-8_3.9x4.9mm_P1.27mm
U2: LM4040DBZ-5; SOT-23
U3: LT3467A; TSOT-23-6
U4: LT1117-3.3; SOT-223-3_TabPin2

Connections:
+3.3VA: C5.1, C6.1, FB2.1; also elsewhere on the board
+3V3: C4.1, C23.1, C24.1, C25.1, C26.1, C27.1, FB2.2, U4.2 (VO); also elsewhere on the board
+9V: D1.1 (K), FB1.2, FB3.2; also elsewhere on the board
+12V: C11.1, C15.1, C17.1, C19.1, C21.1, D3.1 (K), R8.2, U1.8 (V+), U5.8 (V+), U6.8 (V+), U7.8 (V+); also elsewhere on the board
-5V: C14.2, R5.1, U2.2 (A); also elsewhere on the board
-12V: C12.2, C16.2, C18.2, C20.2, C22.2, D5.2 (A), FB4.1, U1.4 (V-), U5.4 (V-), U6.4 (V-), U7.4 (V-); also elsewhere on the board
/power_supply/9VDC_in: D1.2 (A); also elsewhere on the board
GND: C3.2, C4.2, C5.2, C6.2, C7.2, C8.2, C11.2, C12.1, C13.1, C14.1, C15.2, C16.1, C17.2, C18.1, C19.2, C20.1, C21.2, C22.1, C23.2, C24.2, C25.2, C26.2, C27.2, D2.2 (A), D4.1 (K), R9.1, U2.1 (K), U3.2 (GND), U4.1 (GND); also elsewhere on the board
unnamed: C3.1, FB1.1, U4.3 (VI)
unnamed: C7.1, FB3.1, L1.1, U3.4 (~SHDN), U3.6 (Vin)
unnamed: C8.1, U3.5 (SS)
unnamed: C9.2, D4.2 (A), R6.1
unnamed: C10.1, D3.2 (A), R7.2
unnamed: C9.1, C10.2, L1.2, U3.1 (SW)
unnamed: C13.2, FB4.2, R5.2
unnamed: D2.1 (K), R7.1
unnamed: D5.1 (K), R6.2
unnamed: R8.1, R9.2, U3.3 (FB)

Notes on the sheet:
-5 volt reference
+/-12 volt DC-DC converter
3.3 volt regulator
9 volt power entry
Opamp decoupling
DAC decoupling
STM32 decoupling
Opamp power pins

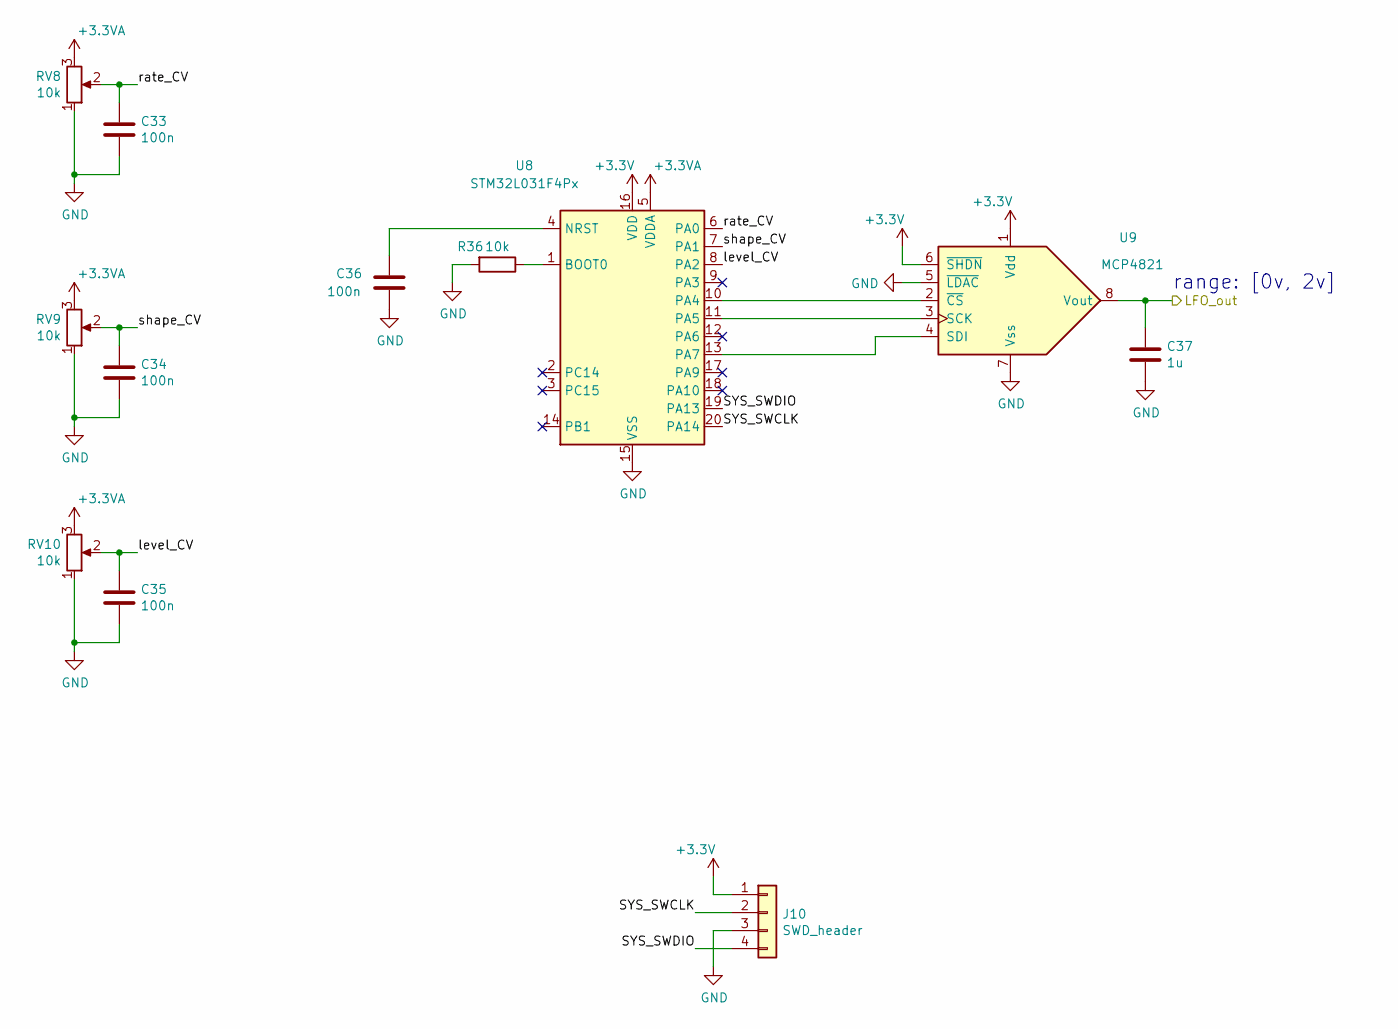
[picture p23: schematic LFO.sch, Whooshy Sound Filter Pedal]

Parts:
C33, C34, C35, C36: 100n; C_0805_2012Metric
C37: 1u; C_0805_2012Metric
J10: SWD_header; PinHeader_1x04_P2.54mm_Vertical
R36: 10k; R_0805_2012Metric
RV8, RV9, RV10: 10k; Potentiometer_Alpha_RD901F-40-00D_Single_Vertical
U8: STM32L031F4Px; TSSOP-20_4.4x6.5mm_P0.65mm
U9: MCP4821; MSOP-8_3x3mm_P0.65mm

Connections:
+3.3VA: RV8.3, RV9.3, RV10.3, U8.5 (VDDA); also elsewhere on the board
+3V3: J10.1, U8.16 (VDD), U9.1 (Vdd), U9.6 (~SHDN); also elsewhere on the board
/cutoff_CV_generator/LFO/LFO_out: C37.1, U9.8 (Vout); also elsewhere on the board
/cutoff_CV_generator/LFO/SYS_SWCLK: J10.2, U8.20 (PA14)
/cutoff_CV_generator/LFO/SYS_SWDIO: J10.4, U8.19 (PA13)
/cutoff_CV_generator/LFO/level_CV: C35.1, RV10.2, U8.8 (PA2)
/cutoff_CV_generator/LFO/rate_CV: C33.1, RV8.2, U8.6 (PA0)
/cutoff_CV_generator/LFO/shape_CV: C34.1, RV9.2, U8.7 (PA1)
GND: C33.2, C34.2, C35.2, C36.2, C37.2, J10.3, R36.2, RV8.1, RV9.1, RV10.1, U8.15 (VSS), U9.5 (~LDAC), U9.7 (Vss); also elsewhere on the board
unnamed: C36.1, U8.4 (NRST)
unnamed: R36.1, U8.1 (BOOT0)
unnamed: U8.10 (PA4), U9.2 (~CS)
unnamed: U8.11 (PA5), U9.3 (SCK)
unnamed: U8.13 (PA7), U9.4 (SDI)

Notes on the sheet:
range: [0v, 2v]

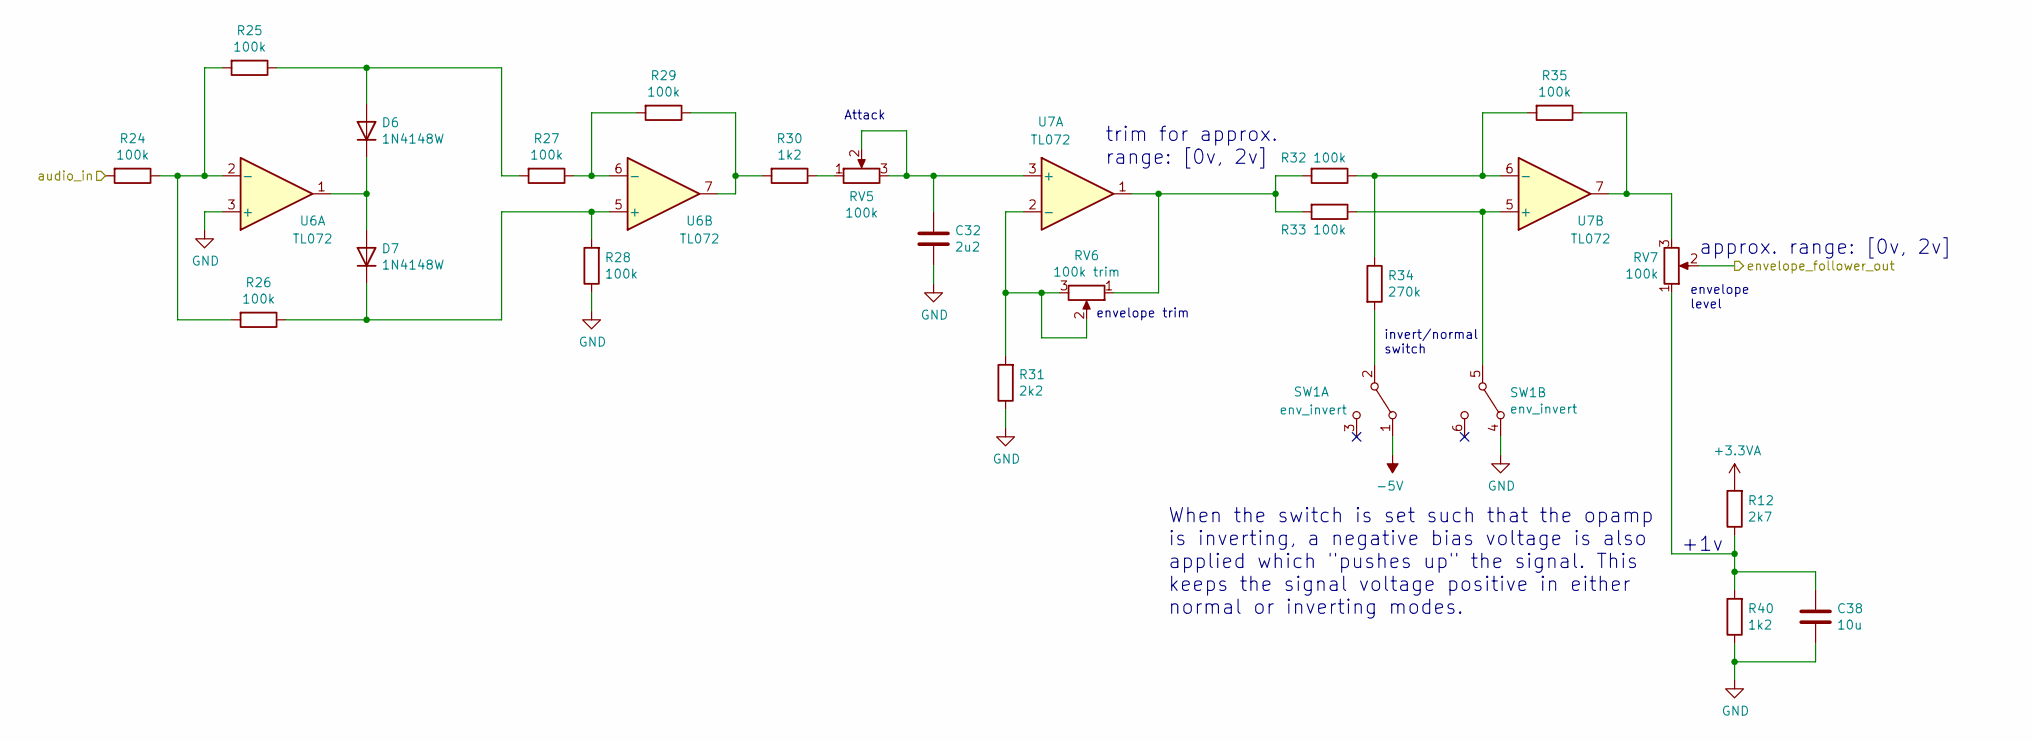
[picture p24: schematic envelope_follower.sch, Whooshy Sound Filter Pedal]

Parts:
C32: 2u2; C_0805_2012Metric
C38: 10u; C_0805_2012Metric
D6, D7: 1N4148W; D_SOD-123
R12: 2k7; R_0805_2012Metric
R24, R25, R26, R27, R28, R29, R32, R33, R35: 100k; R_0805_2012Metric
R30, R40: 1k2; R_0805_2012Metric
R31: 2k2; R_0805_2012Metric
R34: 270k; R_0805_2012Metric
RV5, RV7: 100k; Potentiometer_Alpha_RD901F-40-00D_Single_Vertical
RV6: 100k trim; Potentiometer_Bourns_3296W_Vertical
SW1: env_invert; DPDT_on_on
U6, U7: TL072; SOIC-8_3.9x4.9mm_P1.27mm

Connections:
+3.3VA: R12.2; also elsewhere on the board
-5V: SW1.1 (A); also elsewhere on the board
/cutoff_CV_generator/envelope_follower/envelope_follower_out: RV7.2; also elsewhere on the board
/input_buffer/buffered_dry_signal_out: R24.2; also elsewhere on the board
GND: C32.2, C38.2, R28.1, R31.1, R40.1, SW1.4 (A), U6.3 (+); also elsewhere on the board
unnamed: C32.1, RV5.2, RV5.3, U7.3 (+)
unnamed: C38.1, R12.1, R40.2, RV7.1
unnamed: D6.1 (K), D7.2 (A), U6.1
unnamed: D6.2 (A), R25.1, R27.2
unnamed: D7.1 (K), R26.1, R28.2, U6.5 (+)
unnamed: R24.1, R25.2, R26.2, U6.2 (-)
unnamed: R27.1, R29.2, U6.6 (-)
unnamed: R29.1, R30.2, U6.7
unnamed: R30.1, RV5.1
unnamed: R31.2, RV6.2, RV6.3, U7.2 (-)
unnamed: R32.1, R34.1, R35.2, U7.6 (-)
unnamed: R32.2, R33.2, RV6.1, U7.1
unnamed: R33.1, SW1.5 (B), U7.5 (+)
unnamed: R34.2, SW1.2 (B)
unnamed: R35.1, RV7.3, U7.7

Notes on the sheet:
Attack
envelope trim
trim for approx. range: [0v, 2v]
envelope level
When the switch is set such that the opamp is inverting, a negative bias voltage is also applied which "pushes up" the signal. This keeps the signal voltage positive in either normal or inverting modes.
invert/normal switch
approx. range: [0v, 2v]
+1v

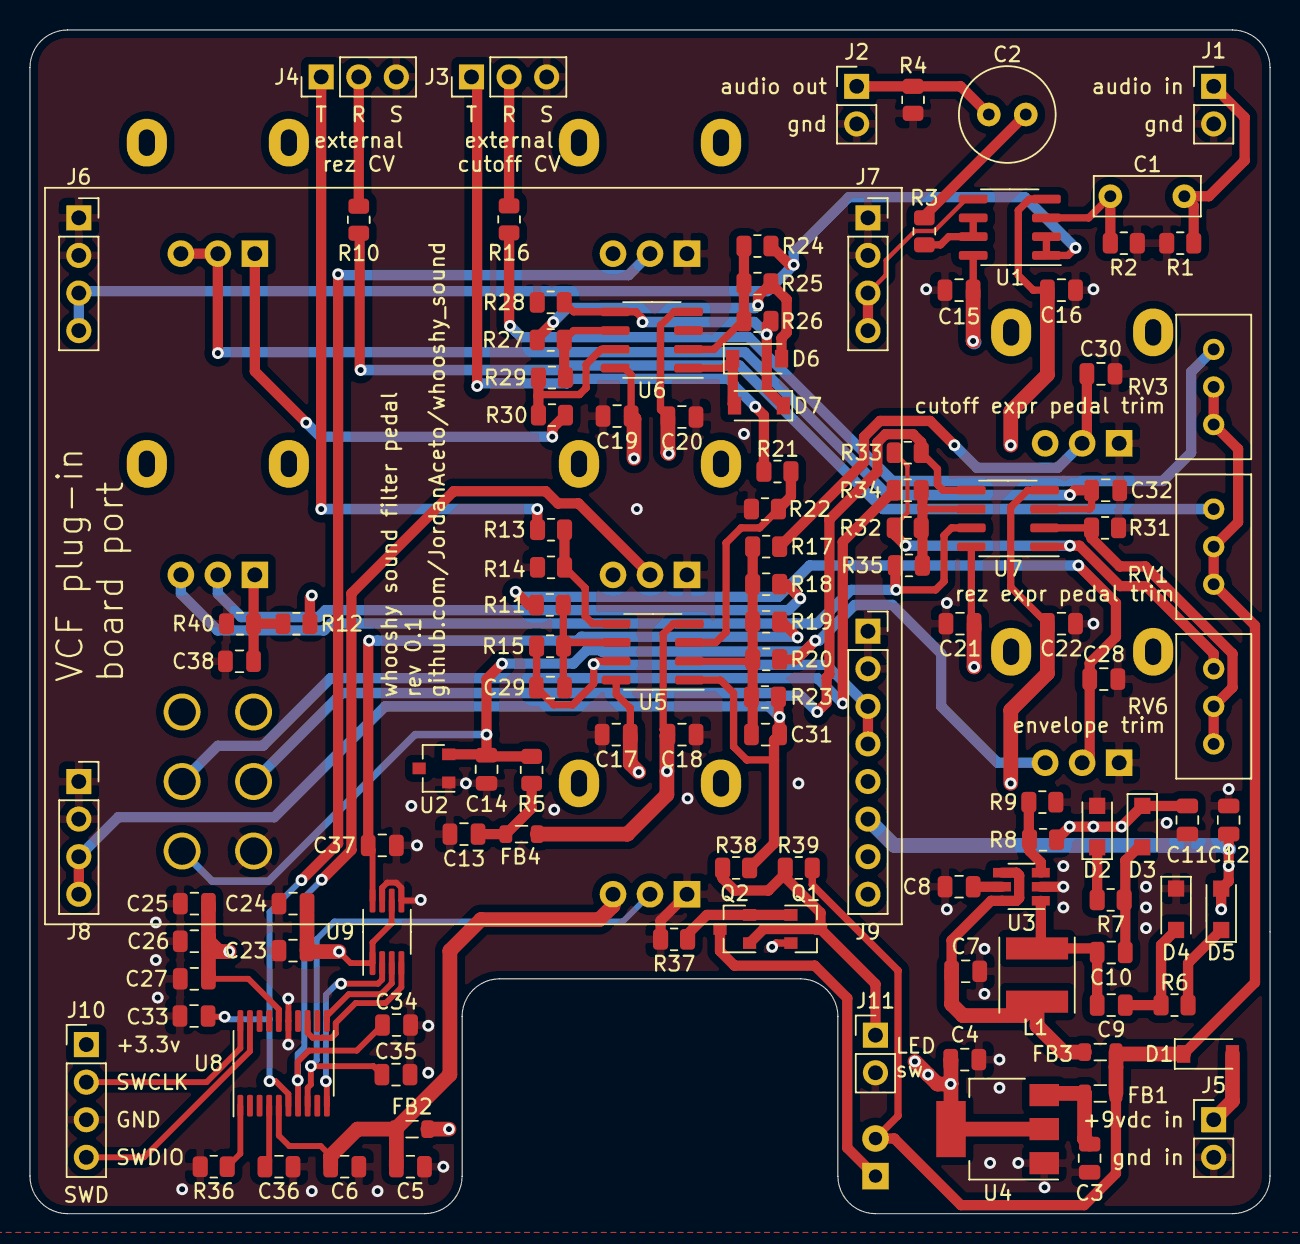
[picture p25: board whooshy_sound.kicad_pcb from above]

Board: 4 copper layers, 83.8 x 80.0 mm, 124 parts (0 on the bottom side), 69 nets.

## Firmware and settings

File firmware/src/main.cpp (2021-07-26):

#include "BSP_ADC1.hpp"
#include "BSP_system_init.hpp"
#include "BSP_TIM2.hpp"
#include "LFO.hpp"
#include "lookup_tables.hpp"
#include "MCP4821.hpp"
#include "stm32l031xx.h"

int main(void)
{
    BSP::system_init::init();

    LFO lfo(BSP::tim2::FREQUENCY_Hz);

    while(1)
    {
        if (BSP::tim2::getTimeout())
        {
            GPIOA->BSRR |= GPIO_BSRR_BS_6; // temporary test code to time execution

            lfo.tick();

            // update the LFO frequency
            const int freq_lut_idx_ui10 = BSP::adc1::getInput(BSP::adc1::LFO_FREQ) >> 6;
            lfo.setInput(LFO::FREQ_mHz, Lookup_Tables::EXPO_MAPPING_LUT_mHz[freq_lut_idx_ui10]);

            // update the LFO wave scanner
            const int wave_scan_ui16 = BSP::adc1::getInput(BSP::adc1::LFO_SHAPE);
            lfo.setInput(LFO::WAVE_SCAN, wave_scan_ui16);

            // attenuate the LFO by the level control and center it in range [0, 0x0FFF] for the DAC
            int scaled_lfo = lfo.getOutput(LFO::CROSSFADED);
            scaled_lfo *= BSP::adc1::getInput(BSP::adc1::LFO_LEVEL);
            scaled_lfo /= (BSP::adc1::FULL_SCALE + 1); // dividing by an exact power of 2 allows for compiler optimizations
            scaled_lfo += LFO::OUTPUT_MAX_VAL;

            MCP4821::write(scaled_lfo);

            GPIOA->BSRR |= GPIO_BSRR_BR_6; // temporary test code to time execution
        }
    }

    // never reached
    return 0;
}

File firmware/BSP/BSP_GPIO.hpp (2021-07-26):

#pragma once

/** @brief General Purpose Input Output pins */
namespace BSP::gpio
{
    /**
     * @brief Initialize the GPIO pins.
     *
     * PA0 is an analog input mapped to the rate CV input.
     * PA1 is an analog input mapped to the shape CV input.
     * PA2 is an analog input mapped to the level CV input.
     *
     * PA4 is SPI1 NSS DAC chip select.
     * PA5 is SPI1 SCK.
     * PA7 is SPI1 MOSI
     *
     * PA13 is SYS SWDIO
     * PA14 is SYS SWCLK
     */
    void init(void);
}

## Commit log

2021-06-18 rough schematic and layout done
    [LFO.sch, cutoff_CV_generator.sch, envelope_follower.sch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]
2021-06-18 tweak pcb
    [whooshy_sound.kicad_pcb]
2021-06-19 start front panel
    [whooshy_sound_front_panel.kicad_pcb]
2021-06-19 move main pcb into its own dir
    [LFO.sch, cutoff_CV_generator.sch, envelope_follower.sch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]
2021-06-19 start drill guides
    [jacks_drill_guide.kicad_pcb]
2021-06-19 start jack panel
    [whooshy_sound_jack_panel.kicad_pcb, whooshy_sound_jack_panel.sch]
2021-06-19 add enclosure specs
2021-06-25 add and demo SPI
2021-06-27 get ADC working and demo
2021-06-27 move DMA module to BSP
2021-06-28 add VCF plug-in boards submodule
2021-06-28 add LED driver, change LED to 5mm
    [cutoff_CV_generator.sch, power_supply.sch, whooshy_sound.kicad_pcb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]
2021-06-28 regenerate BOM and schem
    [whooshy_sound.kicad_pcb]
2021-06-29 tidy up main board
    [LFO.sch, cutoff_CV_generator.sch, envelope_follower.sch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]
2021-06-29 update main pcb pics
2021-06-29 update main board schematic
2021-06-29 generate gerbers
    [whooshy_sound-B_Mask.gbs, whooshy_sound-B_Paste.gbp, whooshy_sound-B_SilkS.gbo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]
2021-06-29 add drill guides
    [whooshy_sound_front_panel_drill_guide.kicad_pcb]
2021-06-29 add panel gerbers
    [whooshy_sound_front_panel-B_Cu.gbl, whooshy_sound_front_panel-B_Mask.gbs, whooshy_sound_front_panel-B_SilkS.gbo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]
2021-06-30 flip env invert switch, condense cap types
    [output_buffer.sch, power_supply.sch, whooshy_sound.kicad_pcb]
2021-06-30 generate jlc pcb assembly docs
    [whooshy_sound_jlc_BOM.csv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]
2021-06-30 regenerate gerbers
    [whooshy_sound-B_Mask.gbs, whooshy_sound-B_Paste.gbp, whooshy_sound-B_SilkS.gbo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]
2021-07-01 add offboard wiring diagram
    [whooshy_sound_offboard_wiring.kicad_pcb, whooshy_sound_offboard_wiring.sch]
2021-07-06 add smt assembly readme
2021-07-12 update drill guides
    [jacks_drill_guide.kicad_pcb, whooshy_sound_drill_guide.kicad_pcb, whooshy_sound_front_panel_drill_guide.kicad_pcb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]
2021-07-14 use correct ADC inputs
2021-07-26 use ADC hardware oversampling
2021-08-05 center envelope follower around +1v, tidy up
    [LFO.sch, cutoff_CV_generator.sch, envelope_follower.sch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]
2022-01-05 add link to schematic
2022-01-16 update vcf boards ref

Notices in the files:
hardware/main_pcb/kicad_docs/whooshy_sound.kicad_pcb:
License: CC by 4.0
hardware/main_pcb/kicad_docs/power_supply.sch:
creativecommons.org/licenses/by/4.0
